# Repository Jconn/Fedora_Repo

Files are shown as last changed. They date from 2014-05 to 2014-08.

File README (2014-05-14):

README file for the MAAV EAGLE git repo

*Do not add gerber files or zip files to the repo

*Edit the .gitignore file with any extensions that for gerber files if encountered

*Don't forget to add your name and email address your local config

*If you find errors in libraries, please fix them imediately or contact the author to report the error.

*You should not trust any of the files in this repo.  PLEASE VERIFY ALL COMPONENTS FOR YOURSELF!

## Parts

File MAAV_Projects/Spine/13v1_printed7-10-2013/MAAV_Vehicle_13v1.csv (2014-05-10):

Part | Value | Device | Package | Description | DIGIEKY# | DIGIKEY | DIGIKEY# | MF | MPN | OC_FARNELL | OC_NEWARK | PARTNUM
C1 | 33pF | C-EUC0402 | C0402 | CAPACITOR, European symbol |  |  | box
C2 | 330uF | C-POL-TANT | C_2917_POL |  |  |  | 478-1811-1-ND
C3 | 0.01uF | C-EUC0603 | C0603 | CAPACITOR, European symbol |  |  | 490-1512-1-ND
C4 | 10uF | C-EUC1206 | C1206 | CAPACITOR, European symbol |  |  | 587-2399-1-ND
C5 | 10uF | C-EUC1206 | C1206 | CAPACITOR, European symbol |  |  | 587-2399-1-ND
C6 | 0.01uF | C-EUC0603 | C0603 | CAPACITOR, European symbol |  |  | 490-1512-1-ND
C7 | 10uF | C-EUC1206 | C1206 | CAPACITOR, European symbol |  |  | 587-2399-1-ND
C8 | 10uF | C-EUC1206 | C1206 | CAPACITOR, European symbol |  |  | 587-2399-1-ND
C9 | 10uF | C-EUC1206 | C1206 | CAPACITOR, European symbol |  |  | 587-2399-1-ND
C10 | 100nF | C-EUC0603 | C0603 | CAPACITOR, European symbol |  |  | 1276-1000-1-ND
C11 | 100nF | C-EUC0603 | C0603 | CAPACITOR, European symbol |  |  | 1276-1000-1-ND
C12 | 100nF | C-EUC0603 | C0603 | CAPACITOR, European symbol |  |  | 1276-1000-1-ND
C13 | 100nF | C-EUC0603 | C0603 | CAPACITOR, European symbol |  |  | 1276-1000-1-ND
C14 | 22pF | C-EUC0603 | C0603 | CAPACITOR, European symbol |  |  | 478-6200-1-ND
C15 | 22pF | C-EUC0603 | C0603 | CAPACITOR, European symbol |  |  | 478-6200-1-ND
C16 | 0.01uF | C-EUC0603 | C0603 | CAPACITOR, European symbol |  |  | 490-1512-1-ND
C17 | 4700pf | C-EUC0402 | C0402 | CAPACITOR, European symbol |  |  | box
C18 | 1uF | C-EUC0603 | C0603 | CAPACITOR, European symbol |  |  | 587-2984-1-ND
C19 | 10uF | C-EUC1206 | C1206 | CAPACITOR, European symbol |  |  | 587-2399-1-ND
C20 | 10uF | C-EUC1206 | C1206 | CAPACITOR, European symbol |  |  | 587-2399-1-ND
C21 | 0.1uF | C-EUC0603 | C0603 | CAPACITOR, European symbol |  |  | 1276-1000-1-ND
C22 | 270pF | C-EUC0402 | C0402 | CAPACITOR, European symbol |  |  | box
C23 | 150uF DNP | T530X157M016ATE015 | C2917 |  |  |  |  |  |  |  |  | 399-4663-1-ND
C24 | 22uF | C-EUC1206 | C1206 | CAPACITOR, European symbol |  |  | 587-3246-1-ND
C25 | 10uF | C-EUC1206 | C1206 | CAPACITOR, European symbol |  |  | 587-2399-1-ND
C26 | 10uF | C-EUC1206 | C1206 | CAPACITOR, European symbol |  |  | 587-2399-1-ND
C27 | 100nF | C-EUC0603 | C0603 | CAPACITOR, European symbol |  |  | 1276-1000-1-ND
C30 | 22uF | C-EUC1206 | C1206 | CAPACITOR, European symbol |  |  | 587-3246-1-ND
C31 | 10uF | C-EUC1206 | C1206 | CAPACITOR, European symbol |  |  | 587-2399-1-ND
C32 | 0.1uF | C-EUC0402 | C0402 | CAPACITOR, European symbol |  |  | box
C33 | 22uF | C-EUC1206 | C1206 | CAPACITOR, European symbol |  |  | 587-3246-1-ND
C34 | 22uF | C-EUC1206 | C1206 | CAPACITOR, European symbol |  |  | 587-3246-1-ND
C35 | 22uF | C-EUC1206 | C1206 | CAPACITOR, European symbol |  |  | 587-3246-1-ND
C36 | 22uF | C-EUC1206 | C1206 | CAPACITOR, European symbol |  |  | 587-3246-1-ND
C37 | 0.1uF | C-EUC0603 | C0603 | CAPACITOR, European symbol |  |  | 490-1524-1-ND
C38 | 0.47uF | C-EUC0805 | C0805 | CAPACITOR, European symbol |  |  | 1276-2966-1-ND
C39 | 0.47uF | C-EUC0805 | C0805 | CAPACITOR, European symbol |  |  | 1276-2966-1-ND
C40 | 0.47uF | C-EUC0805 | C0805 | CAPACITOR, European symbol |  |  | 1276-2966-1-ND
C41 | 0.1uF | C-EUC0603 | C0603 | CAPACITOR, European symbol |  |  | 490-1524-1-ND
C42 | 470uF | C-POL-AL-8-22 | EH22-9 |  | P14440-ND
C43 | 470uF | C-POL-AL-8-22 | EH22-9 |  | P14440-ND
D1 | PDS760 | PDS760 | PDS760 |  |  |  | PDS760DICT-ND
IC3 | PINTO_SMD | PINTO_SMD | PINTO_SMD |  |  |  | S5641-ND (6)
J7 | MA04-1 | MA04-1 | MA-04-SMD |  |  |  | 455-1751-1-ND
J9 | POWER_CONN | POWER_CONN | POWER_CONN |  |  | A30614-ND
L2 | 10uH | DRQ125 | DRQ125 |  |  |  |  |  |  |  |  | 513-1289-1-ND
LED1 | GREEN | LEDCHIPLED_0603 | CHIPLED_0603 | LED |  |  | 1080-1405-1-ND
LED2 | GREEN | LEDCHIPLED_0603 | CHIPLED_0603 | LED |  |  | 1080-1405-1-ND
LED3 | GREEN | LEDCHIPLED_0603 | CHIPLED_0603 | LED |  |  | 1080-1405-1-ND
LED_M0 | GREEN | LEDCHIPLED_0805 | CHIPLED_0805 | LED |  |  | 350-2044-1-ND
LED_M1 | GREEN | LEDCHIPLED_0805 | CHIPLED_0805 | LED |  |  | 350-2044-1-ND
LED_M2 | GREEN | LEDCHIPLED_0805 | CHIPLED_0805 | LED |  |  | 350-2044-1-ND
LED_M3 | GREEN | LEDCHIPLED_0805 | CHIPLED_0805 | LED |  |  | 350-2044-1-ND
Q1 | CRYSTAL_16MHZ_SMD | CRYSTAL_16MHZ_SMD | 4-SMD_DFN |  |  |  | XC1137CT-ND
Q2 | MOSFET-NCHANNELSMD | MOSFET-NCHANNELSMD | SOT23-3 |  |  |  | BSS84CT-ND
Q3 | P-MOSFET-SO8POWER-PAK | P-MOSFET-SO8POWER-PAK | SO-8_POWER-PAK | P-Channel MOSFET |  |  | SI7135DP-T1-GE3CT-ND
Q4 | P-MOSFET-SO8POWER-PAK | P-MOSFET-SO8POWER-PAK | SO-8_POWER-PAK | P-Channel MOSFET |  |  | SI7135DP-T1-GE3CT-ND
Q5 | P-MOSFET-SO8POWER-PAK | P-MOSFET-SO8POWER-PAK | SO-8_POWER-PAK | P-Channel MOSFET |  |  | SI7135DP-T1-GE3CT-ND
Q6 | P-MOSFET-SO8POWER-PAK | P-MOSFET-SO8POWER-PAK | SO-8_POWER-PAK | P-Channel MOSFET |  |  | SI7135DP-T1-GE3CT-ND
Q7 | P-MOSFET-SO8POWER-PAK | P-MOSFET-SO8POWER-PAK | SO-8_POWER-PAK | P-Channel MOSFET |  |  | SI7135DP-T1-GE3CT-ND
Q8 | STL60N3LLH5 | STL60N3LLH5 | POWERFLAT-8 |  |  |  |  |  |  |  |  | 497-11094-1-ND
R1 | 10k | R-USR0603 | R0603 | RESISTOR, American symbol |  |  | P10.0KHCT-ND
R2 | 10k | R-USR0603 | R0603 | RESISTOR, American symbol |  |  | P10.0KHCT-ND
R3 | 10k | R-USR0603 | R0603 | RESISTOR, American symbol |  |  | P10.0KHCT-ND
R4 | 100 | R-USR0402 | R0402 | RESISTOR, American symbol |  |  | box
R5 | 1k | R-USR0603 | R0603 | RESISTOR, American symbol |  |  | P1.00KHCT-ND
R6 | 750 | R-USR0805 | R0805 | RESISTOR, American symbol |  |  | P750CCT-ND
R7 | 10k | R-USR0603 | R0603 | RESISTOR, American symbol |  |  | P10.0KHCT-ND
R8 | 1k | R-USR0603 | R0603 | RESISTOR, American symbol |  |  | P1.00KHCT-ND
R9 | 10k | R-USR0603 | R0603 | RESISTOR, American symbol |  |  | P10.0KHCT-ND
R10 | 10k | R-USR0603 | R0603 | RESISTOR, American symbol |  |  | P10.0KHCT-ND
R11 | 10k | R-USR0603 | R0603 | RESISTOR, American symbol |  |  | P10KDBCT-ND
R12 | 3.16k | R-USR0603 | R0603 | RESISTOR, American symbol |  |  | 311-3.16KDCT-ND
R13 | 10k | R-USR0603 | R0603 | RESISTOR, American symbol |  |  | P10.0KHCT-ND
R14 | 4.7k | R-USR0603 | R0603 | RESISTOR, American symbol |  |  | P4.70KHCT-ND
R15 | 10k | R-USR0603 | R0603 | RESISTOR, American symbol |  |  | P10.0KHCT-ND
R16 | 4.7k | R-USR0603 | R0603 | RESISTOR, American symbol |  |  | P4.70KHCT-ND
R17 | 10k | R-USR0603 | R0603 | RESISTOR, American symbol |  |  | P10.0KHCT-ND
R18 | 4.7k | R-USR0603 | R0603 | RESISTOR, American symbol |  |  | P4.70KHCT-ND
R19 | 10k | R-USR0603 | R0603 | RESISTOR, American symbol |  |  | P10.0KHCT-ND
R20 | 4.7k | R-USR0603 | R0603 | RESISTOR, American symbol |  |  | P4.70KHCT-ND
R21 | 10k | R-USR0603 | R0603 | RESISTOR, American symbol |  |  | P10.0KHCT-ND
R22 | 750 | R-USR0805 | R0805 | RESISTOR, American symbol |  |  | P750CCT-ND
R23 | 750 | R-USR0805 | R0805 | RESISTOR, American symbol |  |  | P750CCT-ND
R24 | 750 | R-USR0805 | R0805 | RESISTOR, American symbol |  |  | P750CCT-ND
R25 | 10k | R-USR0603 | R0603 | RESISTOR, American symbol |  |  | P10.0KHCT-ND
R26 | 10k | R-USR0603 | R0603 | RESISTOR, American symbol |  |  | P10.0KHCT-ND
R27 | 20k | R-USR0402 | R0402 | RESISTOR, American symbol |  |  | box
R28 | 64.9k | R-USR0402 | R0402 | RESISTOR, American symbol |  |  | P64.9KDCCT-ND
R29 | 10k | R-USR0402 | R0402 | RESISTOR, American symbol |  |  | box
R30 | 1k | R-USR0402 | R0402 | RESISTOR, American symbol |  |  | box
R31 | 20k | R-USR0402 | R0402 | RESISTOR, American symbol |  |  | box
R32 | 50 | R-USR0402 | R0402 | RESISTOR, American symbol |  |  | box
R33 | 2.32k | R-USR0402 | R0402 | RESISTOR, American symbol |  |  | P2.32KDCCT-ND
R34 | 27.4k | R-USR0402 | R0402 | RESISTOR, American symbol |  |  | box
R35 | 0.05 | R-US_R2512 | R2512 | RESISTOR, American symbol |  |  | MCS3264R050FERCT-ND
R36 | 10k | R-USR0603 | R0603 | RESISTOR, American symbol |  |  | P10.0KHCT-ND
R37 | 10k | R-USR0603 | R0603 | RESISTOR, American symbol |  |  | P10.0KHCT-ND
R38 | 10k | R-USR0603 | R0603 | RESISTOR, American symbol |  |  | P10.0KHCT-ND
R39 | 10k | R-USR0603 | R0603 | RESISTOR, American symbol |  |  | P10KDBCT-ND
R40 | 432 | R-USR0603 | R0603 | RESISTOR, American symbol |  |  | P432DBCT-ND
R41 |  | R-USR1206 | R1206 | RESISTOR, American symbol |  |  | P100FCT-ND, P68.1FCT-ND, P200FCT-ND
R44 | 750 | R-USR0805 | R0805 | RESISTOR, American symbol |  |  | P750CCT-ND
R47 | 750 | R-USR0805 | R0805 | RESISTOR, American symbol |  |  | P750CCT-ND
R48 | 750 | R-USR0805 | R0805 | RESISTOR, American symbol |  |  | P750CCT-ND
R51 | 10k | R-USR0603 | R0603 | RESISTOR, American symbol |  |  | P10KDBCT-ND
R52 | 432 | R-USR0603 | R0603 | RESISTOR, American symbol |  |  | P432DBCT-ND
S2 | SWITCH-OFF-MOM | SWITCH-OFF-MOM | SWITCH-OFF-MOM |  |  | P11084SCT-ND | P11084SCT-ND
SJ1 | SOLDERJUMPERNO | SOLDERJUMPERNO | SJ_2S-NO | Solder Jumper
SJ2 | SOLDERJUMPERNO | SOLDERJUMPERNO | SJ_2S-NO | Solder Jumper
SJ3 | SOLDERJUMPER_2WAYS | SOLDERJUMPER_2WAYS | SJ_3 | Solder Jumper
SJ4 | SOLDERJUMPER_2WAYS | SOLDERJUMPER_2WAYS | SJ_3 | Solder Jumper
SJ5 | SOLDERJUMPERNO | SOLDERJUMPERNO | SJ_2S-NO | Solder Jumper
SJ6 | SOLDERJUMPER_2WAYS | SOLDERJUMPER_2WAYS | SJ_3 | Solder Jumper
SJ7 | SOLDERJUMPERNO | SOLDERJUMPERNO | SJ_2S-NO | Solder Jumper
SJ8 | SOLDERJUMPER_2WAYS | SOLDERJUMPER_2WAYS | SJ_3 | Solder Jumper
SV1 |  | MA04-1 | MA04-1 | PIN HEADER |  |  |  |  |  | unknown | unknown
SV2 |  | AVRISP-63X2_SMD | AVRISP-6-SMD | PIN HEADER
SV3 |  | MA03-1 | MA03-1 | PIN HEADER |  |  | 3M9477-ND |  |  | unknown | unknown
SV4 |  | MA03-1 | MA03-1 | PIN HEADER |  |  | 3M9477-ND |  |  | unknown | unknown
T1 | MOSFET-NCHANNELSMD | MOSFET-NCHANNELSMD | SOT23-3 |  |  |  | BSS138KCT-ND
T2 | MOSFET-NCHANNELSMD | MOSFET-NCHANNELSMD | SOT23-3 |  |  |  | BSS138KCT-ND
T3 | MOSFET-NCHANNELSMD | MOSFET-NCHANNELSMD | SOT23-3 |  |  |  | BSS138KCT-ND
T4 | MOSFET-NCHANNELSMD | MOSFET-NCHANNELSMD | SOT23-3 |  |  |  | BSS138KCT-ND
T7 | MOSFET-NCHANNELSMD | MOSFET-NCHANNELSMD | SOT23-3 |  |  |  | BSS138KCT-ND
T8 | MOSFET-NCHANNELSMD | MOSFET-NCHANNELSMD | SOT23-3 |  |  |  | BSS138KCT-ND
T9 | MOSFET-NCHANNELSMD | MOSFET-NCHANNELSMD | SOT23-3 |  |  |  | BSS138KCT-ND
T10 | MOSFET-NCHANNELSMD | MOSFET-NCHANNELSMD | SOT23-3 |  |  |  | BSS138KCT-ND
T11 | MOSFET-NCHANNELSMD | MOSFET-NCHANNELSMD | SOT23-3 |  |  |  | BSS138KCT-ND
U$1 | INDUCTOR | INDUCTOR | CDRH127 |  | 308-1333-1-ND | 308-1333-1-ND
U$2 | SWITCH_DPDT | SWITCH_DPDT | SWITCH_VERT_DPDT |  |  |  | AS22AV-ND
U$3 | ESC_CONN | ESC_CONN | ESC_CONN
U$4 | ESC_CONN | ESC_CONN | ESC_CONN
U$5 | ESC_CONN | ESC_CONN | ESC_CONN
U$6 | ESC_CONN | ESC_CONN | ESC_CONN
U$9 | DIODE-SCHOTTKYBIG | DIODE-SCHOTTKYBIG | DO-214AB,SMC |  |  |  | B540C-FDICT-ND
U$10 | TRANSISTOR_NPN_DPAK | TRANSISTOR_NPN_DPAK | DPAK |  |  |  | 497-12849-1-ND
U$11 | MAX3221-RS232 | MAX3221-RS232 | 16-TSSOP |  |  |  | 296-19825-1-ND
U$12 | POWER_HOLES | POWER_HOLES | POWER_HOLES
U$13 | BATTERY50A | BATTERY50A | LIPO_POWER_50A
U$14 | M02_SCREW_0.1 | M02_SCREW_0.1 | SCREW_TERM_2POS |  |  |  | A98333-ND
U$15 | MOSFET-PCHANNEL_SOT23-3 | MOSFET-PCHANNEL_SOT23-3 | SOT23-3 |  |  |  | BSS84CT-ND
U1 | LM5022 | LM5022 | MSOP-10 |  |  |  |  |  |  |  |  | LM5022MM/NOPBCT-ND
U2 | TPS5450 | TPS5450 | TPS5450 |  |  | 296-23750-1-ND | 296-23750-1-ND
U3 | ATMEGA328-AU | ATMEGA328-AU | 32-TQFP |  |  | ATMEGA328-AU-ND | ATMEGA328-AU-ND
U4 | REG_3V_8SOIC | REG_3V_8SOIC | 8-SOIC |  |  | 296-2719-5-ND | 296-2719-5-ND

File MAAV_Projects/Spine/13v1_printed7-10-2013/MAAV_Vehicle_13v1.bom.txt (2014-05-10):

Partlist exported from H:/EAGLE/MAAV/Spine/13v1_printed7-10-2013/MAAV_Vehicle_13v1.sch at 7/13/2013 7:53:38 PMPartlist exported from H:/EAGLE/MAAV/Spine/13v1_printed7-10-2013/MAAV_Vehicle_13v1.sch at 7/13/2013 7:53:38 PM

10,B540C-FDICT-ND
10,A98333-ND
10,296-19825-1-ND
10,BSS84CT-ND
10,AS22AV-ND
10,497-12849-1-ND
10,box
30,490-1524-1-ND
30,490-1512-1-ND
30,1276-2966-1-ND
10,587-2984-1-ND
100,587-2399-1-ND
20,478-6200-1-ND
60,587-3246-1-ND
10,box
50,478-1239-1-ND
10,box
10,478-1811-1-ND
10,box
10,PDS760DICT-ND
10,S5641-ND (6)
10,455-1751-1-ND
30,1080-1405-1-ND
40,350-2044-1-ND
10,XC1137CT-ND
100,BSS84CT-ND
50,SI7135DP-T1-GE3CT-ND
10,P100FCT-ND, P68.1FCT-ND, P200FCT-ND
10,MCS3264R050FERCT-ND
10,box
20,P1.00KHCT-ND
10,P2.32KDCCT-ND
10,311-3.16KDCT-ND
40,P4.70KHCT-ND
10,box
190,P10.0KHCT-ND
20,box
10,box
10,box
10,P64.9KDCCT-ND
10,box
20,P432DBCT-ND
70,P750CCT-ND
10,P11084SCT-ND
20,3M9477-ND
10,ATMEGA328-AU-ND
10,296-2719-5-ND
10,296-23750-1-ND

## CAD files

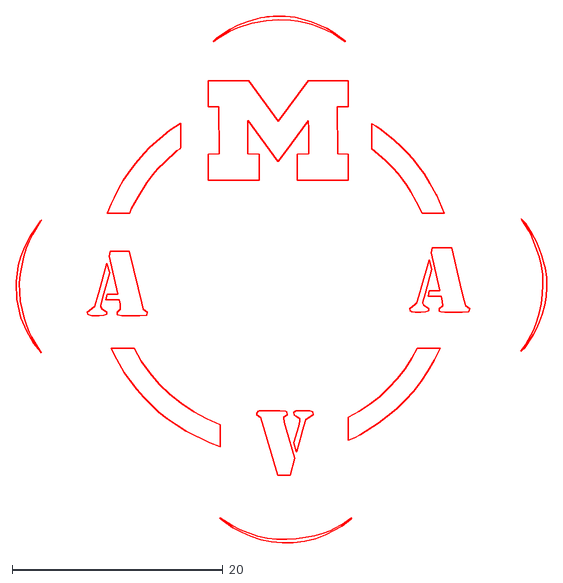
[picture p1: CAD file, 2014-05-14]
Graphics/MAAV Vector Logo.dxf
50.4 x 50.0

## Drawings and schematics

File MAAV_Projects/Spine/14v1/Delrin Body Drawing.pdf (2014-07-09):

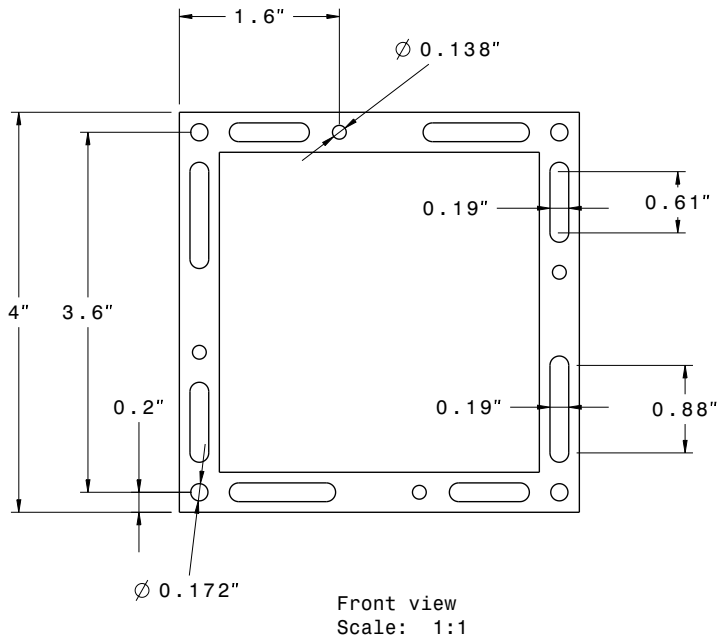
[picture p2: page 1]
Front view Scale: 1:1

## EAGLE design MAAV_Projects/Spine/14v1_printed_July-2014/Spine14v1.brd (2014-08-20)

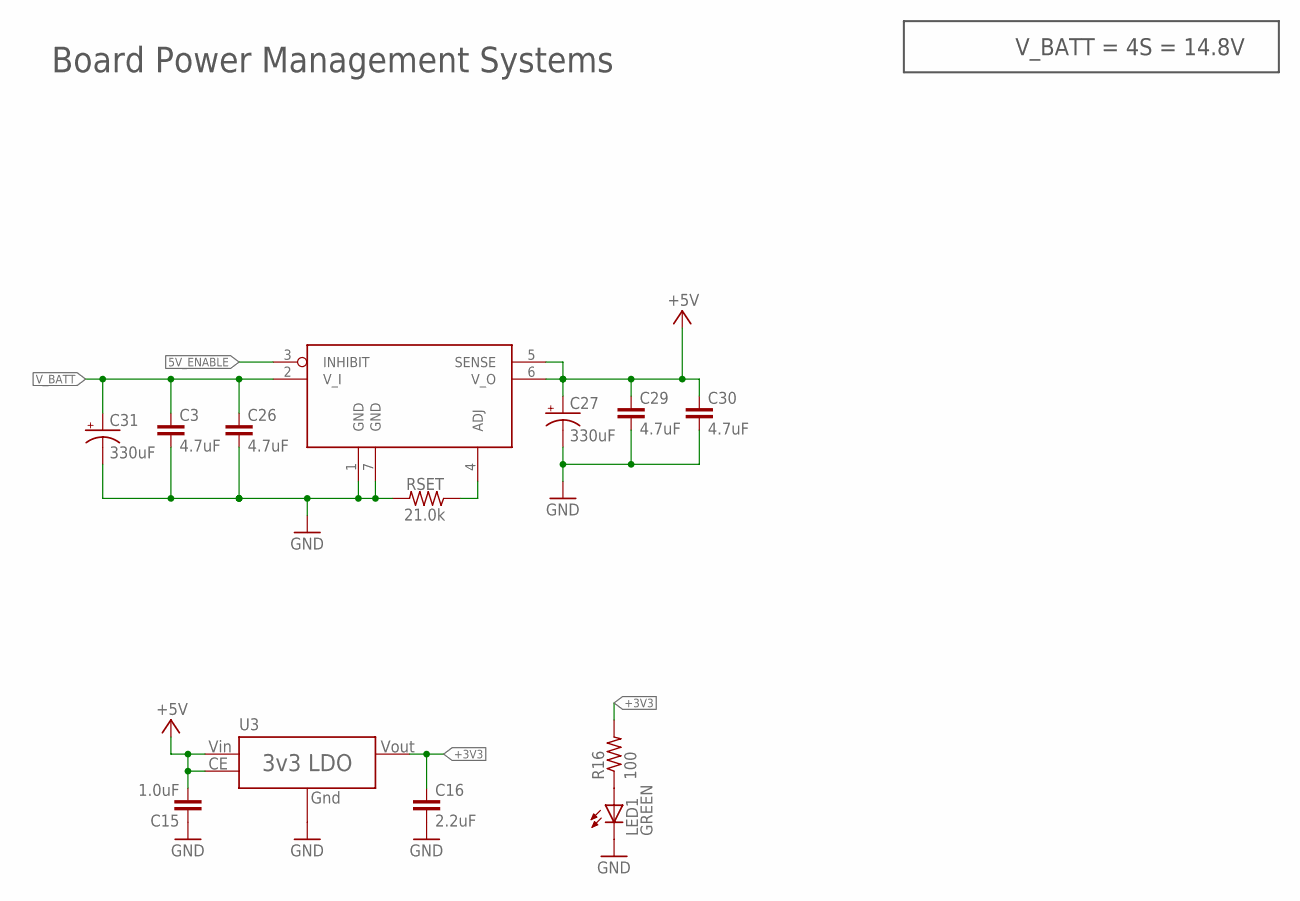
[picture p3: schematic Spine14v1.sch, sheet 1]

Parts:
C3, C26, C29, C30: 4.7uF; C1206; DIGIKEY# 587-2994-1-ND
C15: 1.0uF; C0805
C16: 2.2uF; C0805
C27, C31: 330uF; PANASONIC_F; DIGIKEY PCE3779CT-ND
LED1: GREEN; CHIPLED_0603
R16: 100; R0603
RSET: 21.0k; R0603
U3: XC6210; SOT-25
U$5: POWER-MODULE-TI-6A_SOLDERLESS_TERMINAL; POWER-MOD-TI-6A-SOLDERLESS-TERMINAL

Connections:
5V_ENABLE: U$5.3 (INHIBIT); also elsewhere on the board
+3V3: C16.1, R16.2, U3.5 (VOUT); also elsewhere on the board
+5V: C15.2, C27.+, C29.1, C30.1, U3.1 (VIN), U3.3 (CE), U$5.5 (SENSE), U$5.6 (V_O); also elsewhere on the board
GND: C3.2, C15.1, C16.2, C26.2, C27.-, C29.2, C30.2, C31.-, LED1.C, RSET.2, U3.2 (GND), U$5.1 (GND), U$5.7 (GND); also elsewhere on the board
unnamed: LED1.A, R16.1
unnamed: RSET.1, U$5.4 (ADJ)
V_BATT: C3.1, C26.1, C31.+, U$5.2 (V_I); also elsewhere on the board

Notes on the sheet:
Board Power Management Systems
V_BATT = 4S = 14.8V

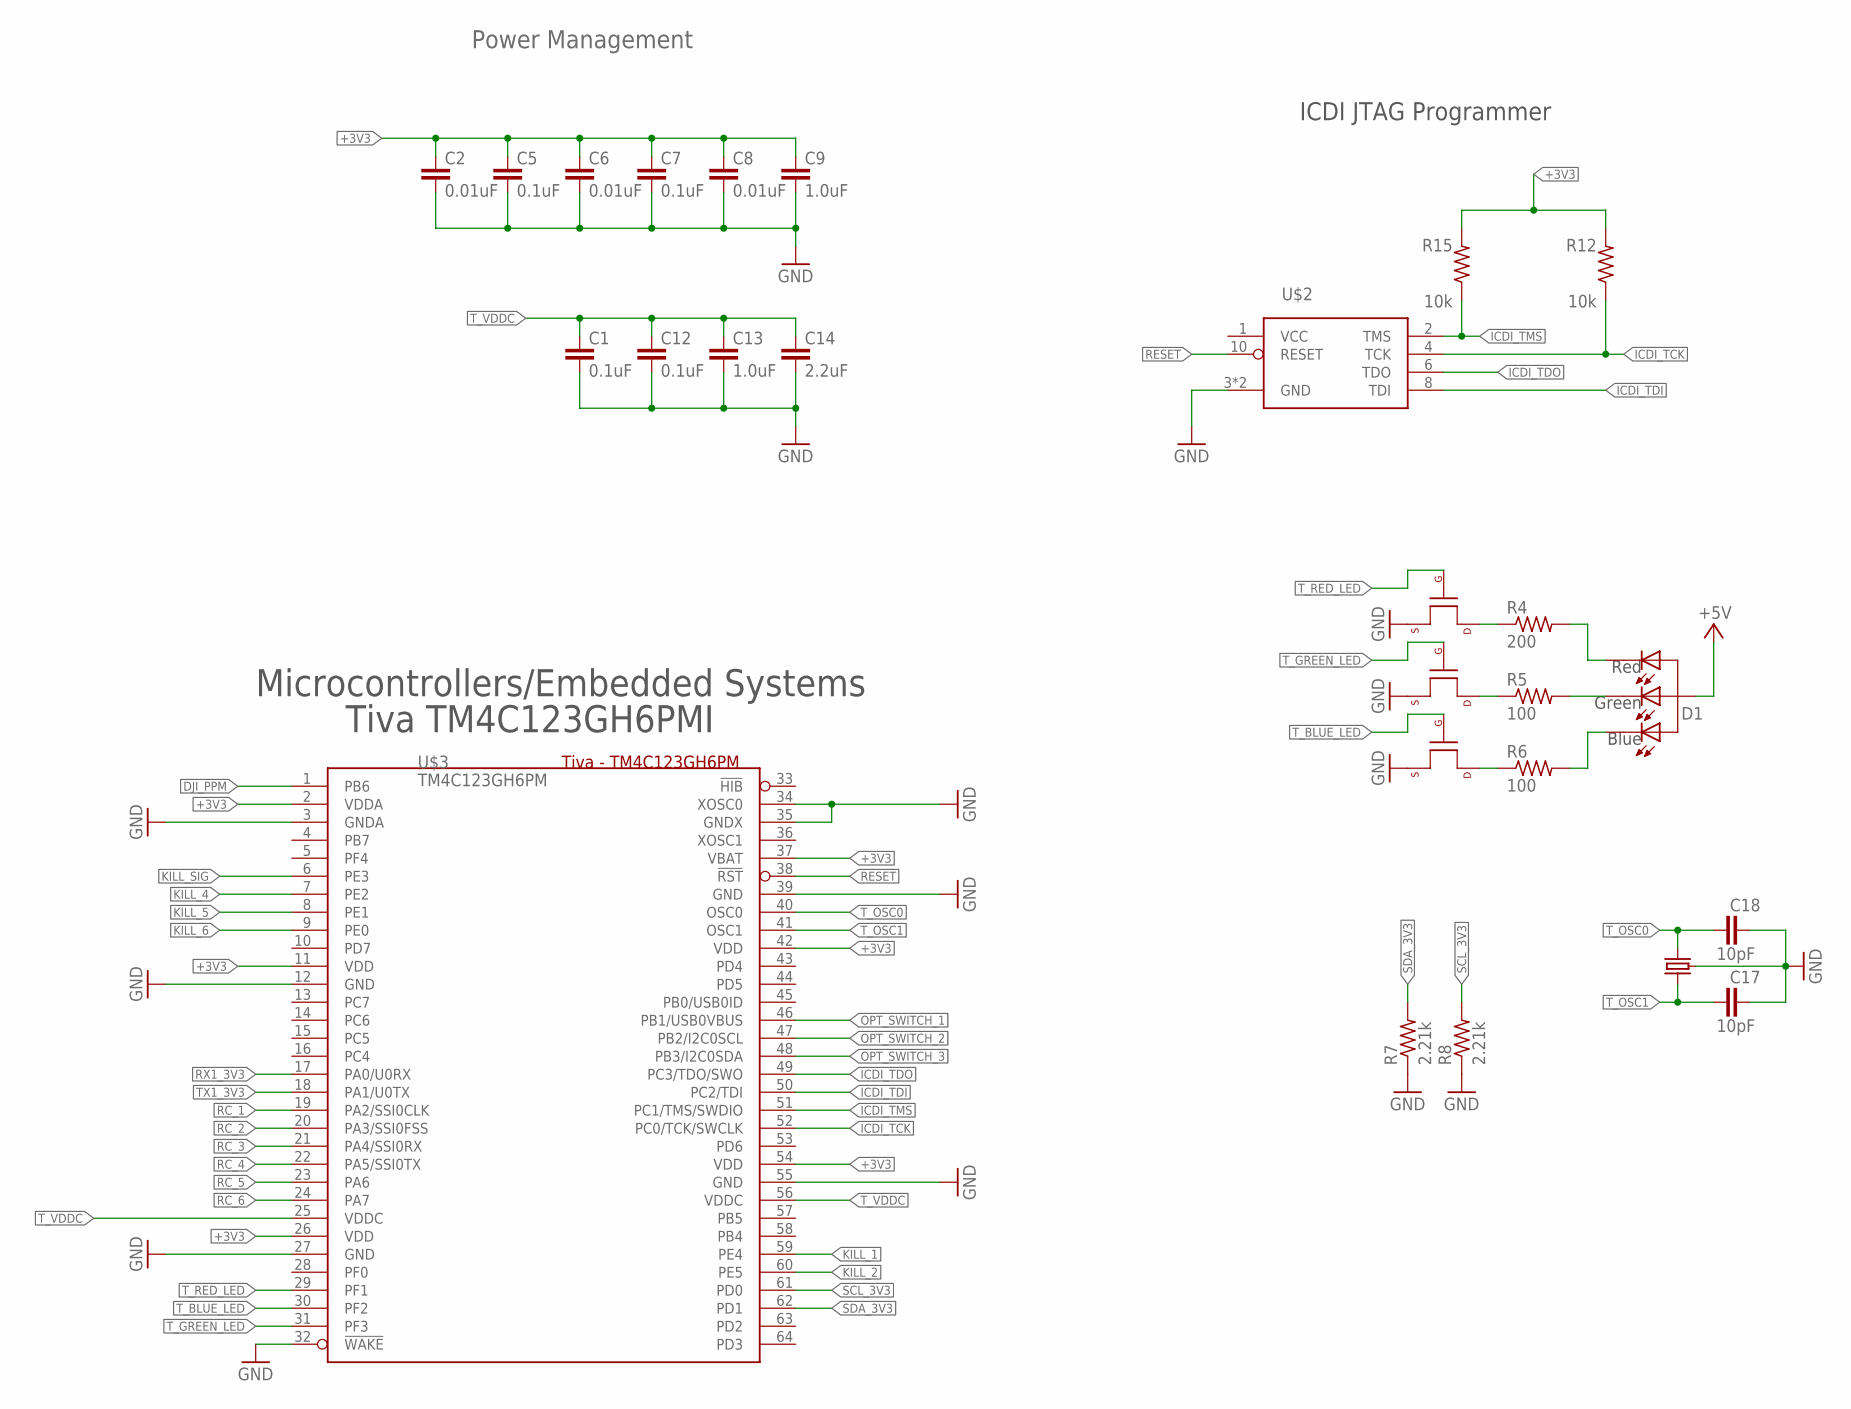
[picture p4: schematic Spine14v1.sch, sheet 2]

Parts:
C1, C5, C7, C12: 0.1uF; C0603
C2, C6, C8: 0.01uF; C0603
C9: 1.0uF; C0603
C13: 1.0uF; C0805
C14: 2.2uF; C0805
C17, C18: 10pF; C0603; DIGIKEY# 399-1049-1-ND
D1: LED_RGB_CA; LED_RGB_0606
Q2, Q3, Q4: MOSFET-NCHANNELSMD; SOT23-3; DIGIKEY# BSN20-7DICT-ND
R4: 200; R0603
R5, R6: 100; R0603
R7, R8: 2.21k; R0603
R12, R15: 10k; R0603
U$1: CRYSTAL_403C11E16; 4-SMD-SWITCH
U$2: JTAG-ARM_TC-10; TC2050-IDC
U$3: TM4C123GH6PM; DIGIKEY# 296-35849-ND

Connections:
+3V3: C2.1, C5.1, C6.1, C7.1, C8.1, C9.1, R12.2, R15.2, U$3.2 (VDDA), U$3.11 (VDD), U$3.26 (VDD), U$3.37 (VBAT), U$3.42 (VDD), U$3.54 (VDD); also elsewhere on the board
+5V: D1.1 (A); also elsewhere on the board
DJI_PPM: U$3.1 (PB6); also elsewhere on the board
GND: C1.2, C2.2, C5.2, C6.2, C7.2, C8.2, C9.2, C12.2, C13.2, C14.2, C17.2, C18.2, Q2.2 (S), Q3.2 (S), Q4.2 (S), R7.1, R8.1, U$1.2 (GND), U$1.4 (GND), U$2.3 (GND), U$2.9 (GND), U$3.3 (GNDA), U$3.12 (GND), U$3.27 (GND), U$3.32 (!WAKE), U$3.34 (XOSC0), U$3.35 (GNDX), U$3.39 (GND), U$3.55 (GND); also elsewhere on the board
ICDI_TCK: R12.1, U$2.4 (TCK), U$3.52 (PC0/TCK/SWCLK)
ICDI_TDI: U$2.8 (TDI), U$3.50 (PC2/TDI)
ICDI_TDO: U$2.6 (TDO), U$3.49 (PC3/TDO/SWO)
ICDI_TMS: R15.1, U$2.2 (TMS), U$3.51 (PC1/TMS/SWDIO)
KILL_1: U$3.59 (PE4); also elsewhere on the board
KILL_2: U$3.60 (PE5); also elsewhere on the board
KILL_4: U$3.7 (PE2); also elsewhere on the board
KILL_5: U$3.8 (PE1); also elsewhere on the board
KILL_6: U$3.9 (PE0); also elsewhere on the board
KILL_SIG: U$3.6 (PE3); also elsewhere on the board
unnamed: Q4.3 (D), R4.1
unnamed: Q3.3 (D), R5.1
unnamed: Q2.3 (D), R6.1
unnamed: D1.2 (R), R4.2
unnamed: D1.3 (G), R5.2
unnamed: D1.4 (B), R6.2
OPT_SWITCH_1: U$3.46 (PB1/USB0VBUS); also elsewhere on the board
OPT_SWITCH_2: U$3.47 (PB2/I2C0SCL); also elsewhere on the board
OPT_SWITCH_3: U$3.48 (PB3/I2C0SDA); also elsewhere on the board
RC_1: U$3.19 (PA2/SSI0CLK); also elsewhere on the board
RC_2: U$3.20 (PA3/SSI0FSS); also elsewhere on the board
RC_3: U$3.21 (PA4/SSI0RX); also elsewhere on the board
RC_4: U$3.22 (PA5/SSI0TX); also elsewhere on the board
RC_5: U$3.23 (PA6); also elsewhere on the board
RC_6: U$3.24 (PA7); also elsewhere on the board
RESET: U$2.10 (RESET), U$3.38 (!RST); also elsewhere on the board
RX1_3V3: U$3.17 (PA0/U0RX); also elsewhere on the board
SCL_3V3: R8.2, U$3.61 (PD0); also elsewhere on the board
SDA_3V3: R7.2, U$3.62 (PD1); also elsewhere on the board
TX1_3V3: U$3.18 (PA1/U0TX); also elsewhere on the board
T_BLUE_LED: Q2.1 (G), U$3.30 (PF2)
T_GREEN_LED: Q3.1 (G), U$3.31 (PF3)
T_OSC0: C18.1, U$1.3 (2), U$3.40 (OSC0)
T_OSC1: C17.1, U$1.1, U$3.41 (OSC1)
T_RED_LED: Q4.1 (G), U$3.29 (PF1)
T_VDDC: C1.1, C12.1, C13.1, C14.1, U$3.25 (VDDC), U$3.56 (VDDC)

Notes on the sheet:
Microcontrollers/Embedded Systems
Power Management
Tiva TM4C123GH6PMI
ICDI JTAG Programmer

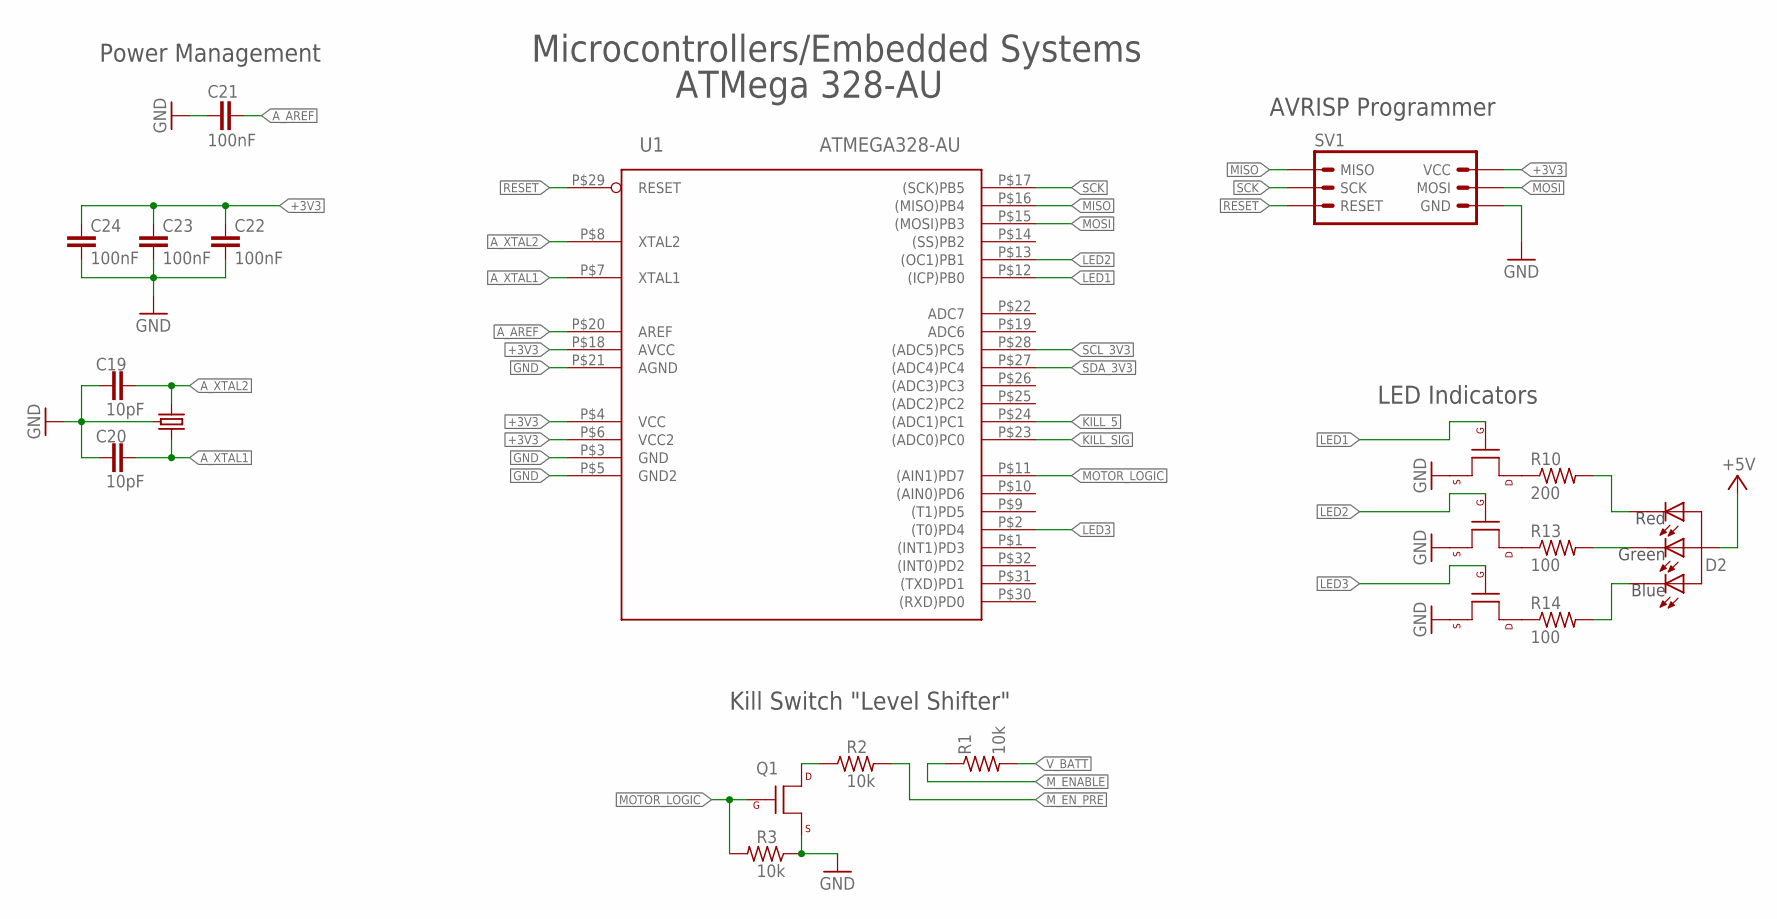
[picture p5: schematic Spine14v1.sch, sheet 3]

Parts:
C19, C20: 10pF; C0603; DIGIKEY# 399-1049-1-ND
C21, C22, C23, C24: 100nF; C0603; DIGIKEY# 1276-1000-1-ND
D2: LED_RGB_CA; LED_RGB_0606
Q1, Q6, Q7, Q8: MOSFET-NCHANNELSMD; SOT23-3; DIGIKEY# BSN20-7DICT-ND
R1, R2, R3: 10k; R0603
R10: 200; R0603
R13, R14: 100; R0603
SV1: AVRISP-6_3X2_PLUG_OF_NAILS; TC2030-IDC
U1: ATMEGA328-AU; 32-TQFP; DIGIKEY# ATMEGA328-AU-ND
U$6: CRYSTAL_403C11E16; 4-SMD-SWITCH

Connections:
+3V3: C22.1, C23.1, C24.1, SV1.6 (VCC), U1.P$4 (VCC), U1.P$6 (VCC2), U1.P$18 (AVCC); also elsewhere on the board
+5V: D2.1 (A); also elsewhere on the board
A_AREF: C21.1, U1.P$20 (AREF)
A_XTAL1: C20.2, U1.P$7 (XTAL1), U$6.3 (2)
A_XTAL2: C19.2, U1.P$8 (XTAL2), U$6.1
GND: C19.1, C20.1, C21.2, C22.2, C23.2, C24.2, Q1.2 (S), Q6.2 (S), Q7.2 (S), Q8.2 (S), R3.1, SV1.4 (GND), U1.P$3 (GND), U1.P$5 (GND2), U1.P$21 (AGND), U$6.2 (GND), U$6.4 (GND); also elsewhere on the board
KILL_5: U1.P$24 ((ADC1)PC1); also elsewhere on the board
KILL_SIG: U1.P$23 ((ADC0)PC0); also elsewhere on the board
LED1: Q8.1 (G), U1.P$12 ((ICP)PB0)
LED2: Q7.1 (G), U1.P$13 ((OC1)PB1)
LED3: Q6.1 (G), U1.P$2 ((T0)PD4)
MISO: SV1.1 (MISO), U1.P$16 ((MISO)PB4)
MOSI: SV1.5 (MOSI), U1.P$15 ((MOSI)PB3)
MOTOR_LOGIC: Q1.1 (G), R3.2, U1.P$11 ((AIN1)PD7)
M_ENABLE: R1.1; also elsewhere on the board
M_EN_PRE: R2.2; also elsewhere on the board
unnamed: Q1.3 (D), R2.1
unnamed: Q8.3 (D), R10.1
unnamed: Q7.3 (D), R13.1
unnamed: Q6.3 (D), R14.1
unnamed: D2.2 (R), R10.2
unnamed: D2.3 (G), R13.2
unnamed: D2.4 (B), R14.2
RESET: SV1.3 (RESET), U1.P$29 (RESET); also elsewhere on the board
SCK: SV1.2 (SCK), U1.P$17 ((SCK)PB5)
SCL_3V3: U1.P$28 ((ADC5)PC5); also elsewhere on the board
SDA_3V3: U1.P$27 ((ADC4)PC4); also elsewhere on the board
V_BATT: R1.2; also elsewhere on the board

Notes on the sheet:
Microcontrollers/Embedded Systems
ATMega 328-AU
AVRISP Programmer
Power Management
LED Indicators
Kill Switch "Level Shifter"

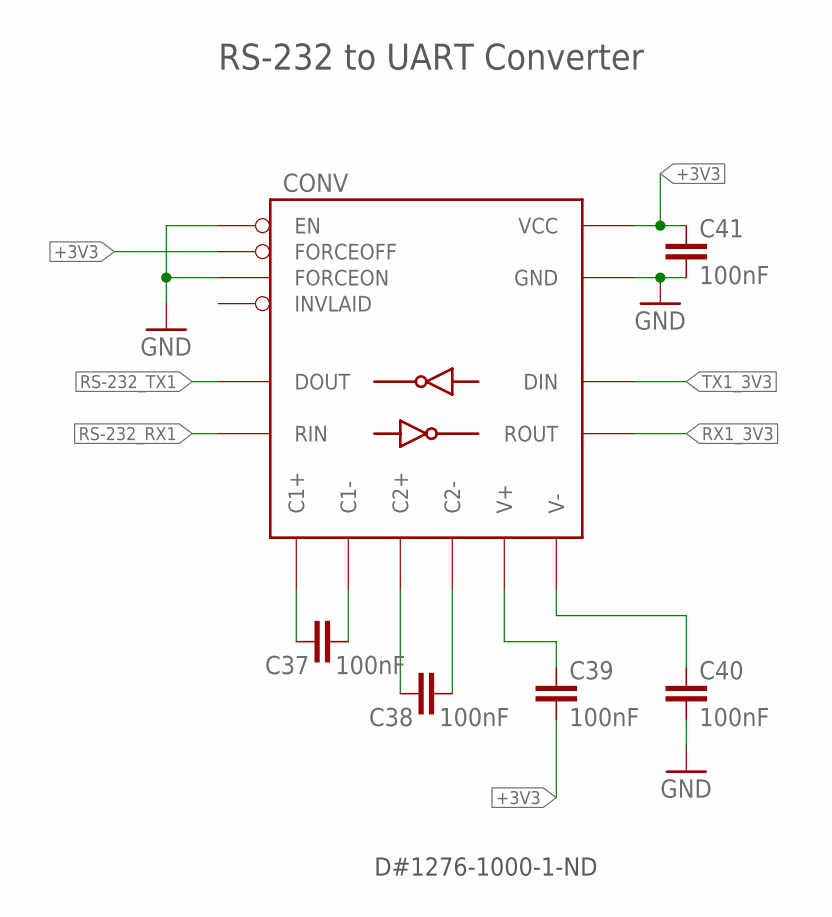
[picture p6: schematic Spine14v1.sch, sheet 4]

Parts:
C37, C41: 100nF; C0603; DIGIKEY# 1276-1000-1-ND
C38, C39, C40: 100nF; C0805
CONV: MAX3221-RS232; 16-TSSOP; DIGIKEY# 296-19825-1-ND

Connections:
+3V3: C39.2, C41.1, CONV.P$15 (VCC), CONV.P$16 (FORCEOFF); also elsewhere on the board
GND: C40.2, C41.2, CONV.P$1 (EN), CONV.P$12 (FORCEON), CONV.P$14 (GND); also elsewhere on the board
unnamed: C37.1, CONV.P$2 (C1+)
unnamed: C39.1, CONV.P$3 (V+)
unnamed: C40.1, CONV.P$7 (V-)
unnamed: C37.2, CONV.P$4 (C1-)
unnamed: C38.1, CONV.P$5 (C2+)
unnamed: C38.2, CONV.P$6 (C2-)
RS-232_RX1: CONV.P$8 (RIN); also elsewhere on the board
RS-232_TX1: CONV.P$13 (DOUT); also elsewhere on the board
RX1_3V3: CONV.P$9 (ROUT); also elsewhere on the board
TX1_3V3: CONV.P$11 (DIN); also elsewhere on the board

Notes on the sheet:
RS-232 to UART Converter
D#1276-1000-1-ND

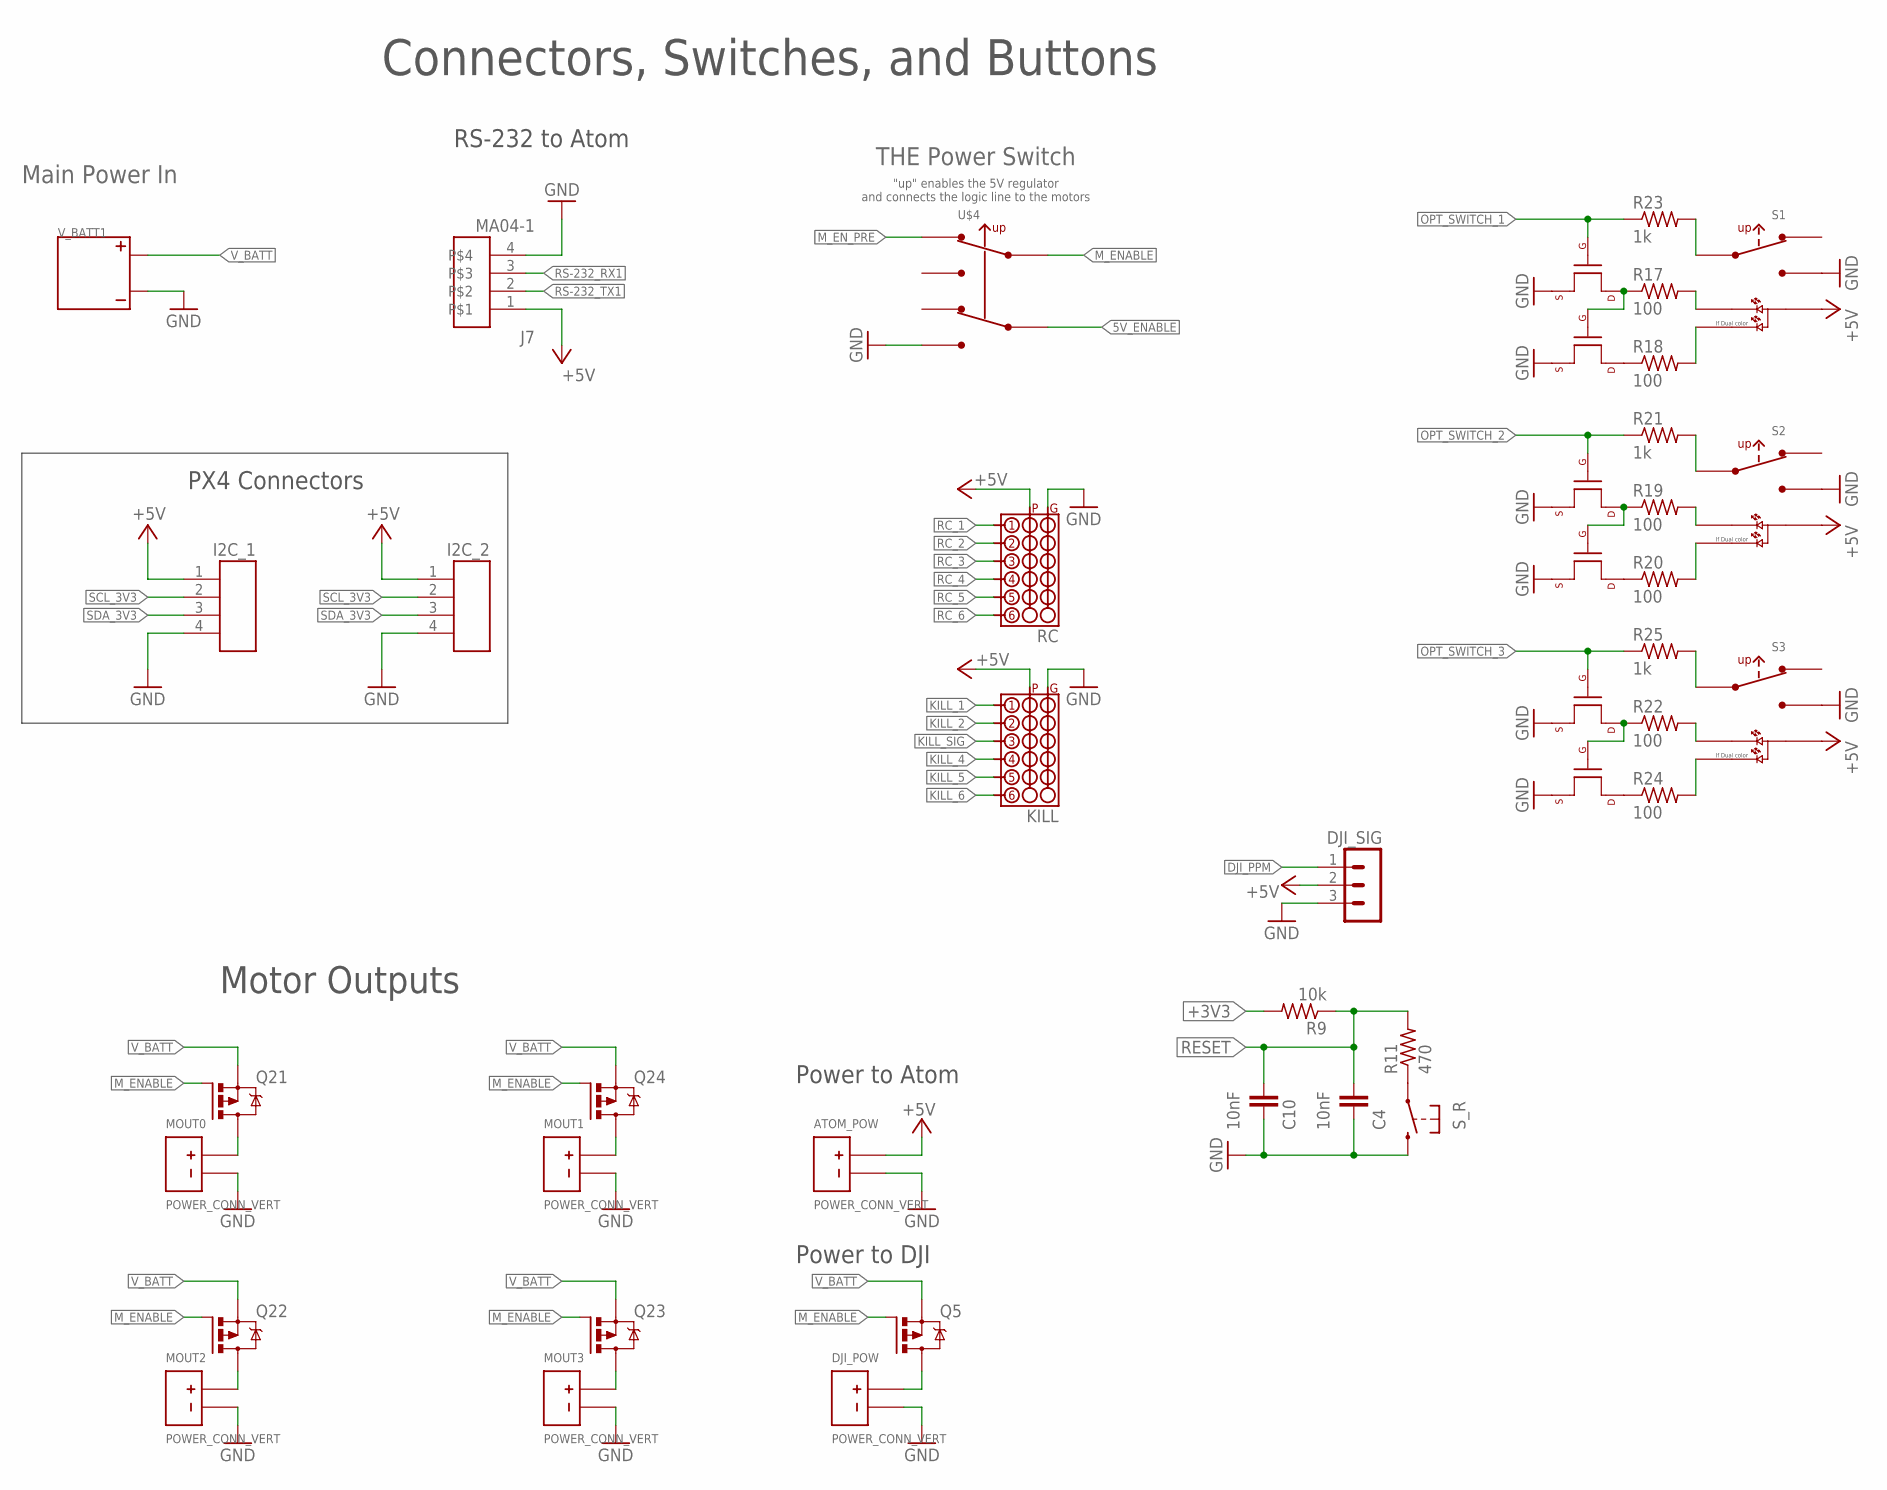
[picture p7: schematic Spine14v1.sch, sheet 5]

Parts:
ATOM_POW: POWER_CONN_VERT; POWER_CONN
C4, C10: 10nF; C0603
DJI_POW: POWER_CONN_VERT; POWER_CONN
DJI_SIG: MA03-1
I2C_1, I2C_2: CONN_HEADER_4POS_RIGHT_ANGLE_I2C; CONN_HEADER_4POS_1.25MM_SMD
J7: MA04-1; MA-04-SMD
KILL: RC_RECIEVER_RECEP
MOUT0, MOUT1, MOUT2, MOUT3: POWER_CONN_VERT; POWER_CONN
Q5, Q21, Q22, Q23, Q24: P-MOSFET-SO8POWER-PAK; SO-8_POWER-PAK
Q9, Q10, Q11, Q12, Q13, Q14: MOSFET-NCHANNELSMD; SOT23-3; DIGIKEY# BSN20-7DICT-ND
R9: 10k; R0603
R11: 470; R0603
R17, R18, R19, R20, R22, R24: 100; R0603
R21, R23, R25: 1k; R0603
RC: RC_RECIEVER_RECEP
S1, S2, S3: SWITCH_SPDT_ILUMINATED_2COLOR_VERT_ILLUMINATED; NKK_VERT_SWITCH_6PIN
S_R: TACT_BUTTONSMD; TACT-MOM-SMD
U$4: JON_LIB_SWITCH_DPDT; JON_LIB_SWITCH_VERT_DPDT
V_BATT1: BATT-CONN-50A_MINI-FIT-SR_THRU-HOLE; BATT-CONN-50A

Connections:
5V_ENABLE: U$4.P$5; also elsewhere on the board
+3V3: R9.2; also elsewhere on the board
+5V: ATOM_POW.P1, DJI_SIG.2, I2C_1.1, I2C_2.1, J7.1, KILL.VCC, KILL.VCC2 (VCC), RC.VCC, RC.VCC2 (VCC), S1.P$5, S2.P$5, S3.P$5; also elsewhere on the board
DJI_PPM: DJI_SIG.1; also elsewhere on the board
GND: ATOM_POW.P2 (N), C4.2, C10.2, DJI_POW.P2 (N), DJI_SIG.3, I2C_1.4, I2C_2.4, J7.4, KILL.GND, KILL.GND2 (GND), MOUT0.P2 (N), MOUT1.P2 (N), MOUT2.P2 (N), MOUT3.P2 (N), Q9.2 (S), Q10.2 (S), Q11.2 (S), Q12.2 (S), Q13.2 (S), Q14.2 (S), RC.GND, RC.GND2 (GND), S1.P$1, S2.P$1, S3.P$1, S_R.S, S_R.S1 (S), U$4.P$6, V_BATT1.GND-1 (GND), V_BATT1.GND-2 (GND); also elsewhere on the board
KILL_1: KILL.P$1; also elsewhere on the board
KILL_2: KILL.P$2; also elsewhere on the board
KILL_4: KILL.P$4; also elsewhere on the board
KILL_5: KILL.P$5; also elsewhere on the board
KILL_6: KILL.P$6; also elsewhere on the board
KILL_SIG: KILL.P$3; also elsewhere on the board
M_ENABLE: Q5.G, Q21.G, Q22.G, Q23.G, Q24.G, U$4.P$2; also elsewhere on the board
M_EN_PRE: U$4.P$1; also elsewhere on the board
unnamed: MOUT0.P1, Q21.D1, Q21.D2 (D1), Q21.D3 (D1), Q21.D4 (D1), Q21.D5 (D1)
unnamed: Q9.1 (G), Q10.3 (D), R17.1
unnamed: R11.1, S_R.P, S_R.P1
unnamed: MOUT1.P1, Q24.D1, Q24.D2 (D1), Q24.D3 (D1), Q24.D4 (D1), Q24.D5 (D1)
unnamed: MOUT2.P1, Q22.D1, Q22.D2 (D1), Q22.D3 (D1), Q22.D4 (D1), Q22.D5 (D1)
unnamed: MOUT3.P1, Q23.D1, Q23.D2 (D1), Q23.D3 (D1), Q23.D4 (D1), Q23.D5 (D1)
unnamed: DJI_POW.P1, Q5.D1, Q5.D2 (D1), Q5.D3 (D1), Q5.D4 (D1), Q5.D5 (D1)
unnamed: Q9.3 (D), R18.1
unnamed: Q11.1 (G), Q12.3 (D), R19.1
unnamed: Q11.3 (D), R20.1
unnamed: R19.2, S2.P$6
unnamed: R20.2, S2.P$4
unnamed: R23.2, S1.P$2
unnamed: R21.2, S2.P$2
unnamed: R17.2, S1.P$6
unnamed: R18.2, S1.P$4
unnamed: Q13.1 (G), Q14.3 (D), R22.1
unnamed: Q13.3 (D), R24.1
unnamed: R22.2, S3.P$6
unnamed: R24.2, S3.P$4
unnamed: R25.2, S3.P$2
OPT_SWITCH_1: Q10.1 (G), R23.1; also elsewhere on the board
OPT_SWITCH_2: Q12.1 (G), R21.1; also elsewhere on the board
OPT_SWITCH_3: Q14.1 (G), R25.1; also elsewhere on the board
RC_1: RC.P$1; also elsewhere on the board
RC_2: RC.P$2; also elsewhere on the board
RC_3: RC.P$3; also elsewhere on the board
RC_4: RC.P$4; also elsewhere on the board
RC_5: RC.P$5; also elsewhere on the board
RC_6: RC.P$6; also elsewhere on the board
RESET: C4.1, C10.1, R9.1, R11.2; also elsewhere on the board
RS-232_RX1: J7.3; also elsewhere on the board
RS-232_TX1: J7.2; also elsewhere on the board
SCL_3V3: I2C_1.2, I2C_2.2; also elsewhere on the board
SDA_3V3: I2C_1.3, I2C_2.3; also elsewhere on the board
V_BATT: Q5.S1, Q5.S2 (S1), Q5.S3 (S1), Q21.S1, Q21.S2 (S1), Q21.S3 (S1), Q22.S1, Q22.S2 (S1), Q22.S3 (S1), Q23.S1, Q23.S2 (S1), Q23.S3 (S1), Q24.S1, Q24.S2 (S1), Q24.S3 (S1), V_BATT1.VCC-1 (VCC), V_BATT1.VCC-2 (VCC); also elsewhere on the board

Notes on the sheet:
Connectors, Switches, and Buttons
"up" enables the 5V regulator and connects the logic line to the motors
Main Power In
THE Power Switch
Motor Outputs
PX4 Connectors
RS-232 to Atom
Power to Atom
Power to DJI

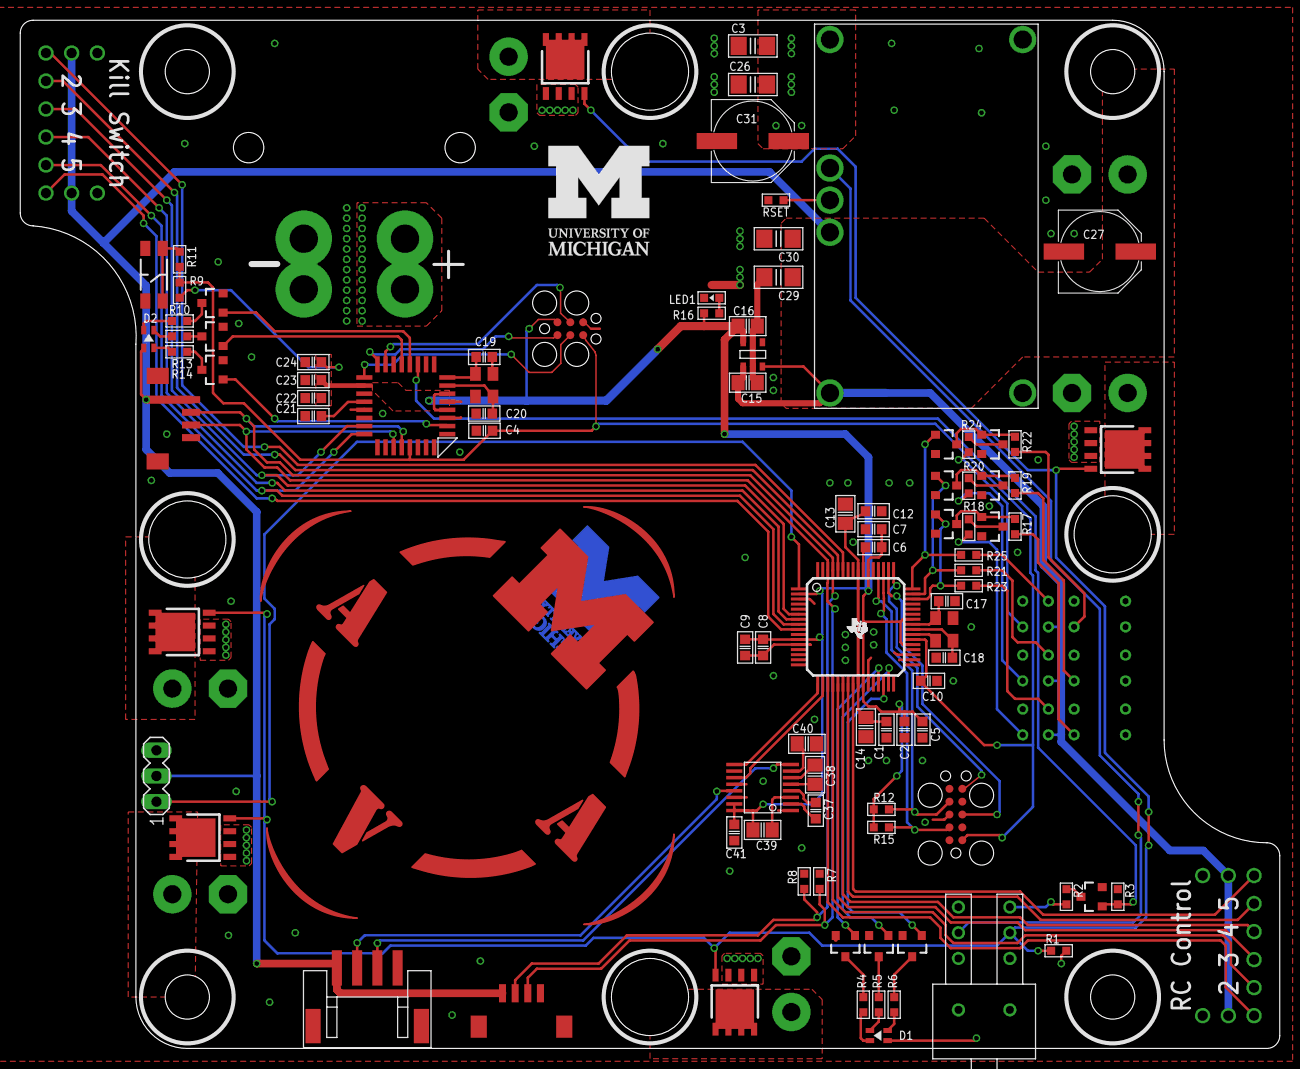
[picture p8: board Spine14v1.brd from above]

Board: 4 copper layers, 124.5 x 101.6 mm, 110 parts (1 on the bottom side), 92 nets.

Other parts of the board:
U$7: BLOCK-M-DOUBLE-STACKED-10MM-MASK
U$8: MAAVLOGO_50MM_MASK_ONLY
U$9: BLOCK-M-DOUBLE-STACKED-10MM

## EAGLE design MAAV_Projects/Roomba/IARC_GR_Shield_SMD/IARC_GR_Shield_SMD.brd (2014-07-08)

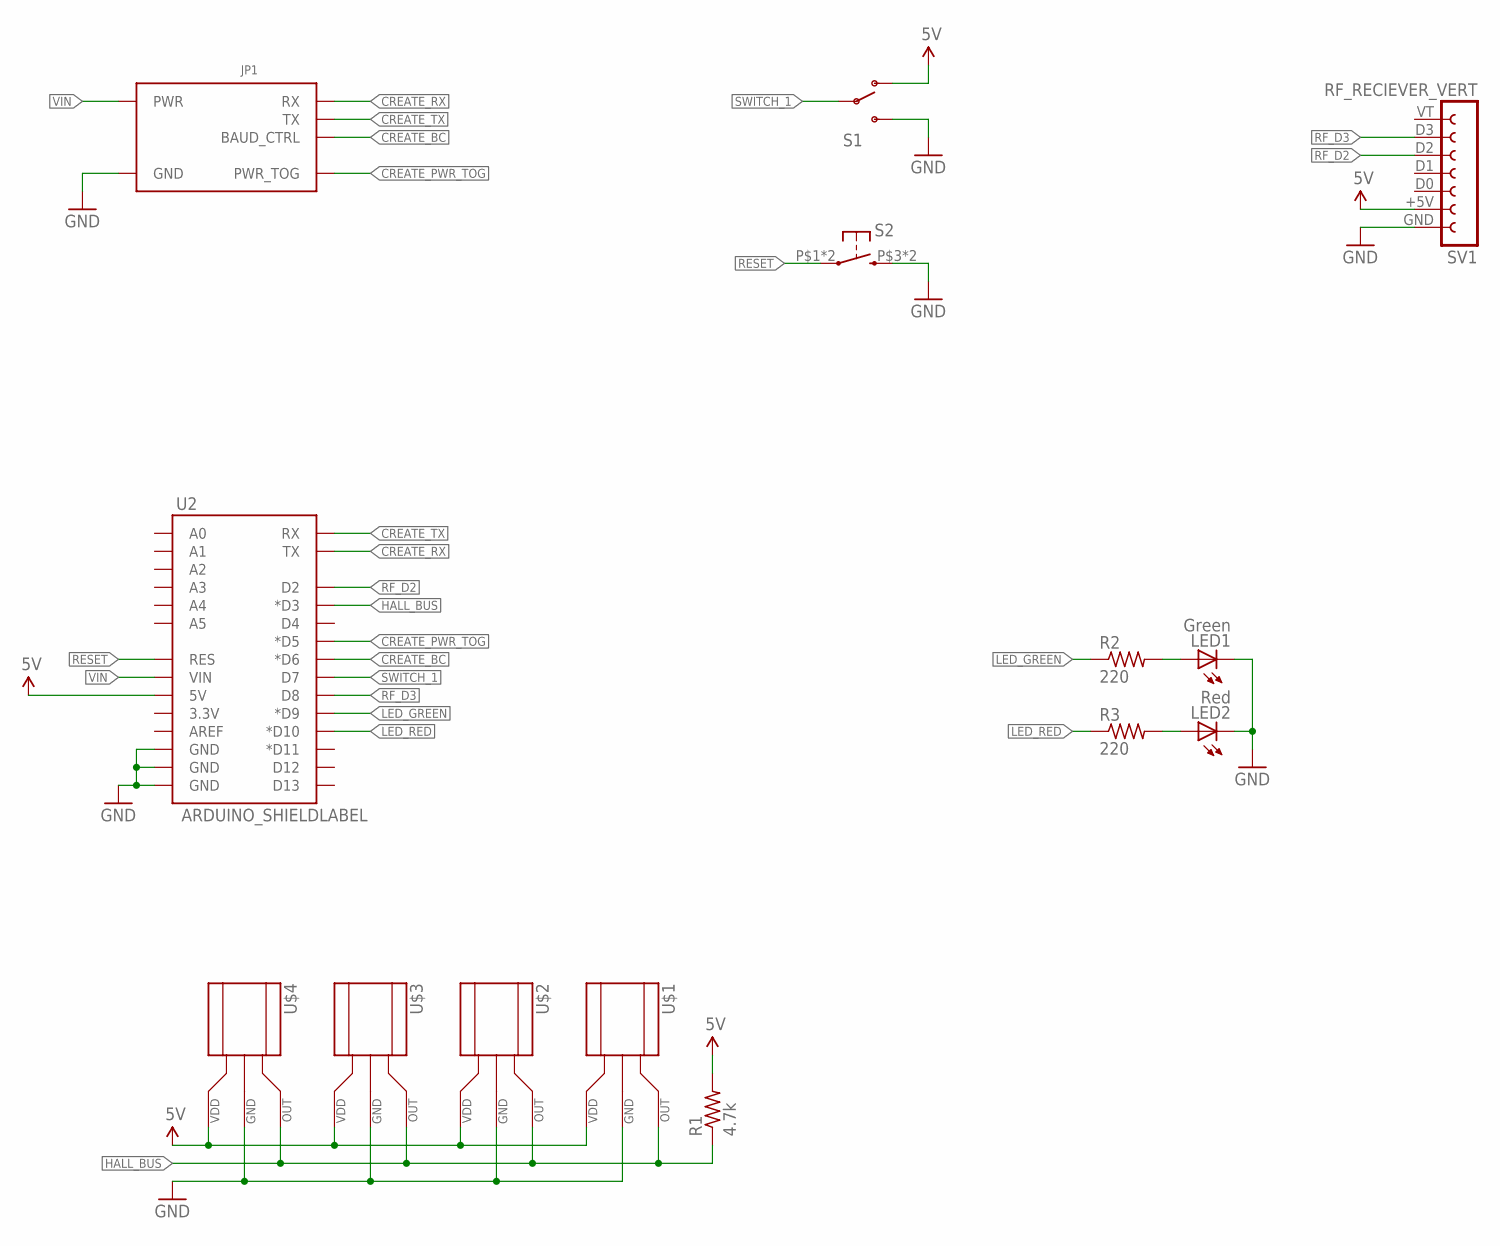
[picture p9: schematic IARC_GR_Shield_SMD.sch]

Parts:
JP1: IROBOT_CREATE_IARC_HOOKUP; 2X5-SHROUDED
LED1: Green; CHIPLED_0603
LED2: Red; CHIPLED_0603
R1: 4.7k; R0603
R2, R3: 220; R0603; DIGIKEY# P220HCT-ND
S1: SWITCH-SPDTTHRU-VERT; SWITCH-SPDT_THRU-VERT
S2: TACT_BUTTON_SMD; SIMPLE_BUTTON_SMD
SV1: RF_RECIEVER_VERT
U2: ARDUINO_SHIELDLABEL; DUEMILANOVE_SHIELD
U$1, U$2, U$3, U$4: HALL_EFFECTHEADER; 1X03

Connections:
5V: R1.2, S1.1 (O), SV1.+5V, U2.5V, U$1.1 (VDD), U$2.1 (VDD), U$3.1 (VDD), U$4.1 (VDD)
CREATE_BC: JP1.3 (BAUD_CTRL), U2.D6 (*D6)
CREATE_PWR_TOG: JP1.5 (PWR_TOG), U2.D5 (*D5)
CREATE_RX: JP1.4 (RX), U2.TX
CREATE_TX: JP1.1 (TX), U2.RX
GND: JP1.2 (GND), LED1.C, LED2.C, S1.3 (S), S2.P$3 (S), S2.P$4 (S), SV1.GND, U2.GND@0 (GND), U2.GND@1 (GND), U2.GND@2 (GND), U$1.2 (GND), U$2.2 (GND), U$3.2 (GND), U$4.2 (GND)
HALL_BUS: R1.1, U2.D3 (*D3), U$1.3 (OUT), U$2.3 (OUT), U$3.3 (OUT), U$4.3 (OUT)
LED_GREEN: R2.1, U2.D9 (*D9)
LED_RED: R3.1, U2.D10 (*D10)
unnamed: LED1.A, R2.2
unnamed: LED2.A, R3.2
RESET: S2.P$1, S2.P$2, U2.RES
RF_D2: SV1.D2, U2.D2
RF_D3: SV1.D3, U2.D8
SWITCH_1: S1.2, U2.D7
VIN: JP1.6 (PWR), U2.VIN

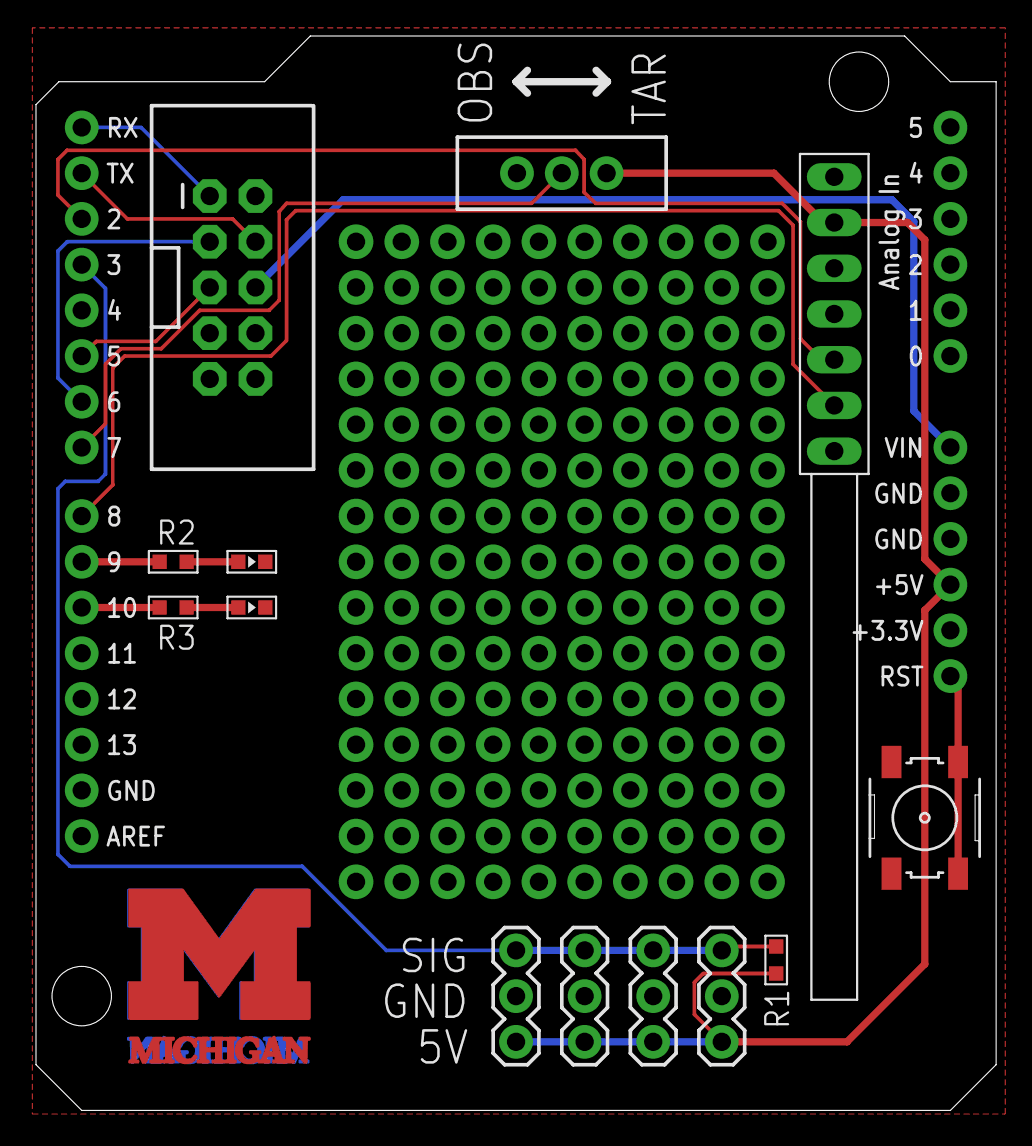
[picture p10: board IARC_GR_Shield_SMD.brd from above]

Board: 2 copper layers, 53.3 x 59.7 mm, 16 parts (1 on the bottom side), 16 nets.

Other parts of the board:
U$12, U$13: BLOCK-M-STACKED_10MM_MASK

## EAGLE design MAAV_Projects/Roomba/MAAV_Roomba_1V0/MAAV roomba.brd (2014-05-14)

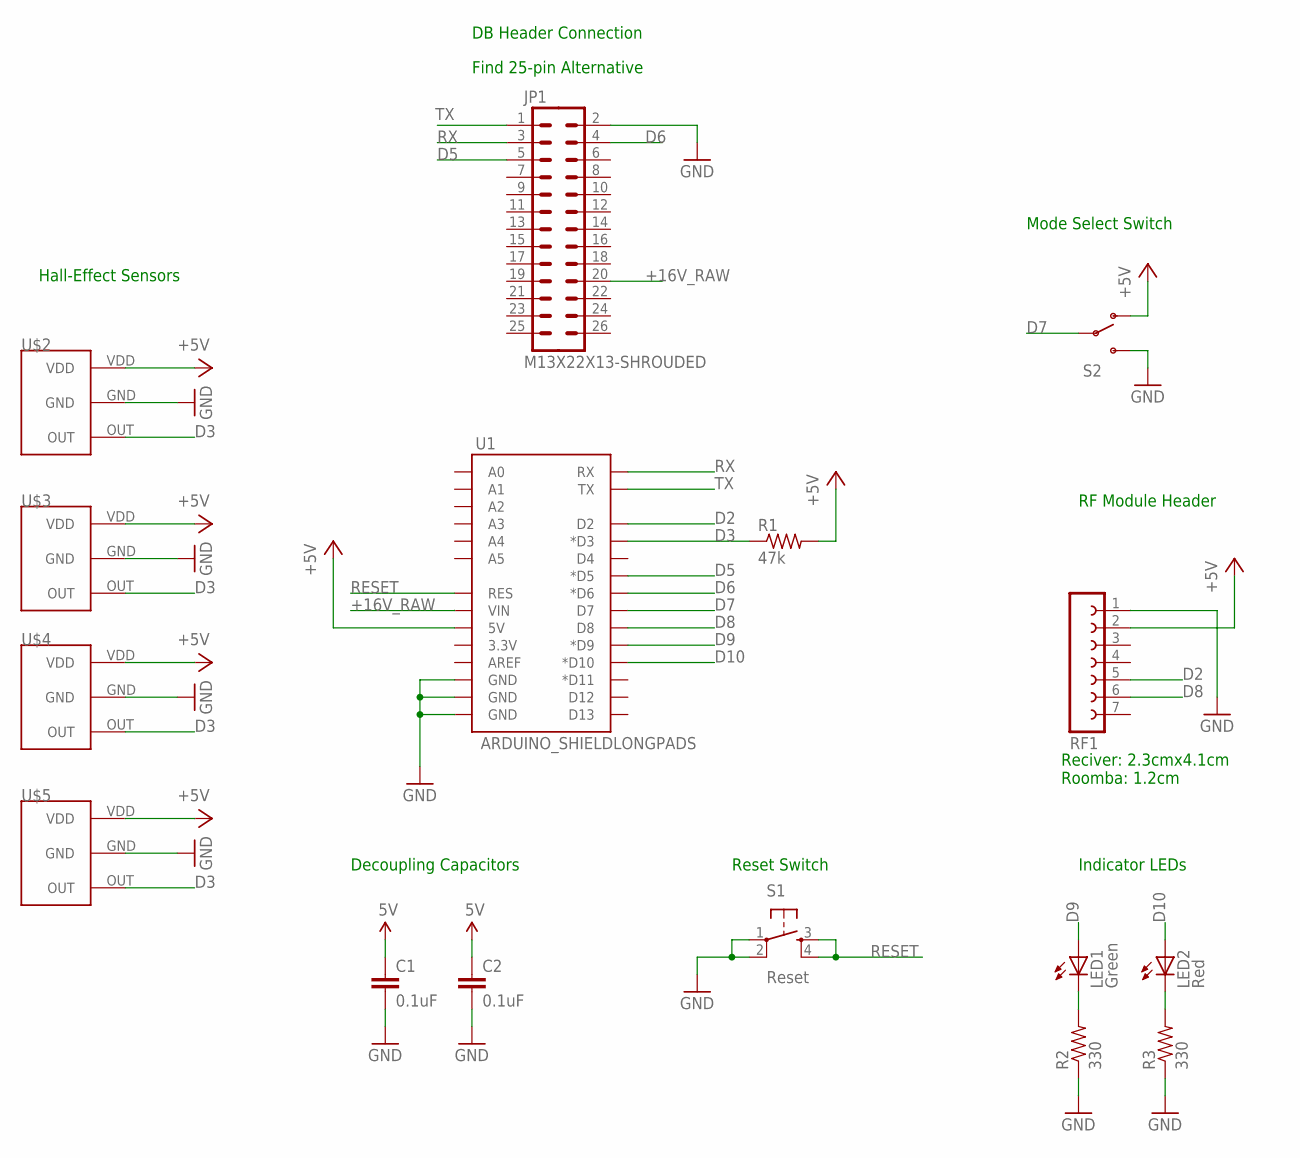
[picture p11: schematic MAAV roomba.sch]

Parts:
C1, C2: 0.1uF; CAP-PTH-SMALL2; DIGIKEY 399-4264-ND
JP1: M13X22X13-SHROUDED; 2X25-SHROUDED
LED1: Green; LED5MM; DIGIKEY 1125-1184-ND
LED2: Red; LED5MM; DIGIKEY 1125-1188-ND
R1: 47k; 0309/10; DIGIKEY CF12JT47K0
R2, R3: 330; AXIAL-0.4; DIGIKEY 330QBK-ND
RF1: FE07W; DIGIKEY S5443-ND
S1: Reset; TACTILE-PTH; DIGIKEY 450-1650-ND
S2: SWITCH-SPDTPTH; SWITCH-SPDT; DIGIKEY EG1903-ND
U1: ARDUINO_SHIELDLONGPADS; DUEMILANOVE_SHIELD_LONGPADS
U$2, U$3, U$4, U$5: HALL_EFFECT; MOUSER 621-AH180-PL-A

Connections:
5V: C1.1, C2.1, R1.2, RF1.2, S2.1 (O), U1.5V, U$2.VDD, U$3.VDD, U$4.VDD, U$5.VDD
+16V_RAW: JP1.20, U1.VIN
D2: RF1.5, U1.D2
D3: R1.1, U1.D3 (*D3), U$2.OUT, U$3.OUT, U$4.OUT, U$5.OUT
D5: JP1.5, U1.D5 (*D5)
D6: JP1.4, U1.D6 (*D6)
D7: S2.2, U1.D7
D8: RF1.6, U1.D8
D9: LED1.A, U1.D9 (*D9)
D10: LED2.A, U1.D10 (*D10)
GND: C1.2, C2.2, JP1.2, R2.P$1 (1), R3.P$1 (1), RF1.1, S1.1, S1.2, S2.3 (S), U1.GND@0 (GND), U1.GND@1 (GND), U1.GND@2 (GND), U$2.GND, U$3.GND, U$4.GND, U$5.GND
unnamed: LED1.K (C), R2.P$2 (2)
unnamed: LED2.K (C), R3.P$2 (2)
RESET: S1.3, S1.4, U1.RES
RX: JP1.3, U1.RX
TX: JP1.1, U1.TX

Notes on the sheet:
Hall-Effect Sensors
DB Header Connection
Find 25-pin Alternative
Decoupling Capacitors
Indicator LEDs
Reset Switch
Mode Select Switch
RF Module Header
Reciver: 2.3cmx4.1cm Roomba: 1.2cm

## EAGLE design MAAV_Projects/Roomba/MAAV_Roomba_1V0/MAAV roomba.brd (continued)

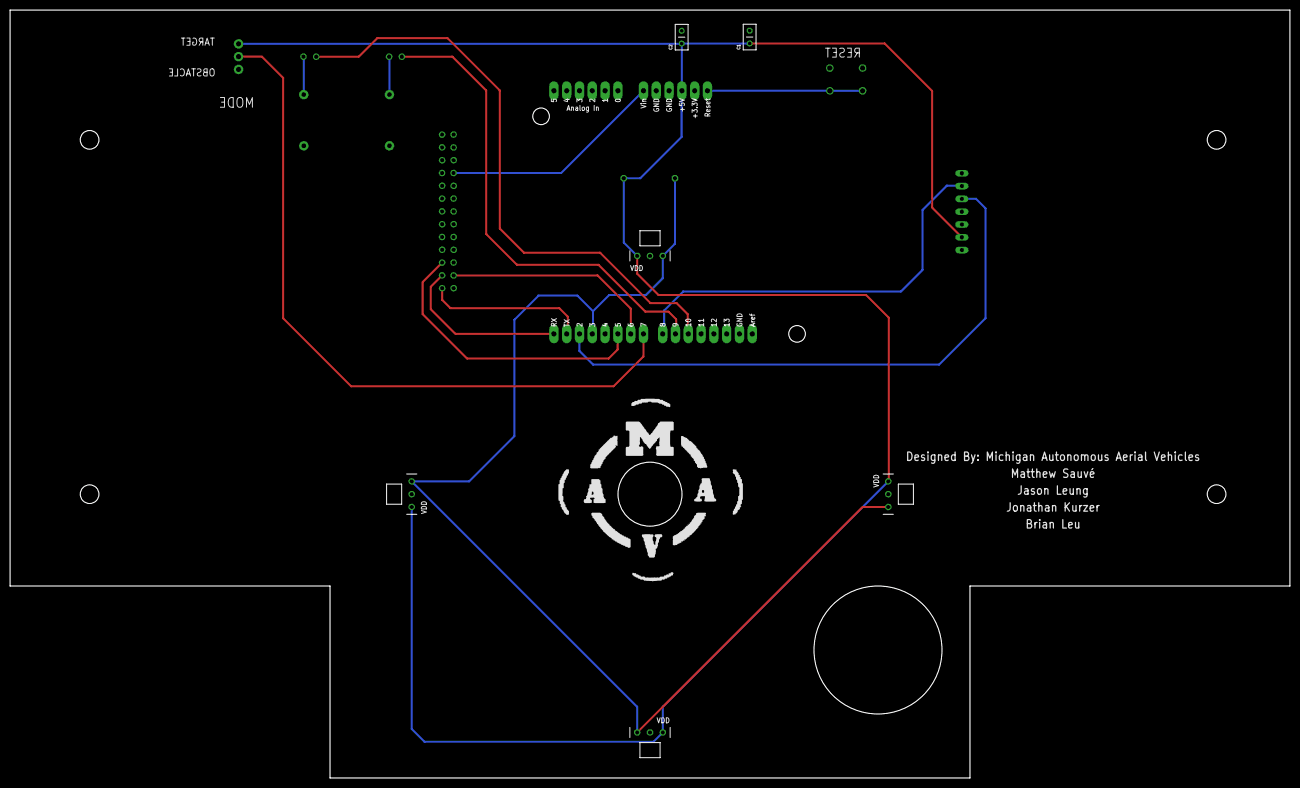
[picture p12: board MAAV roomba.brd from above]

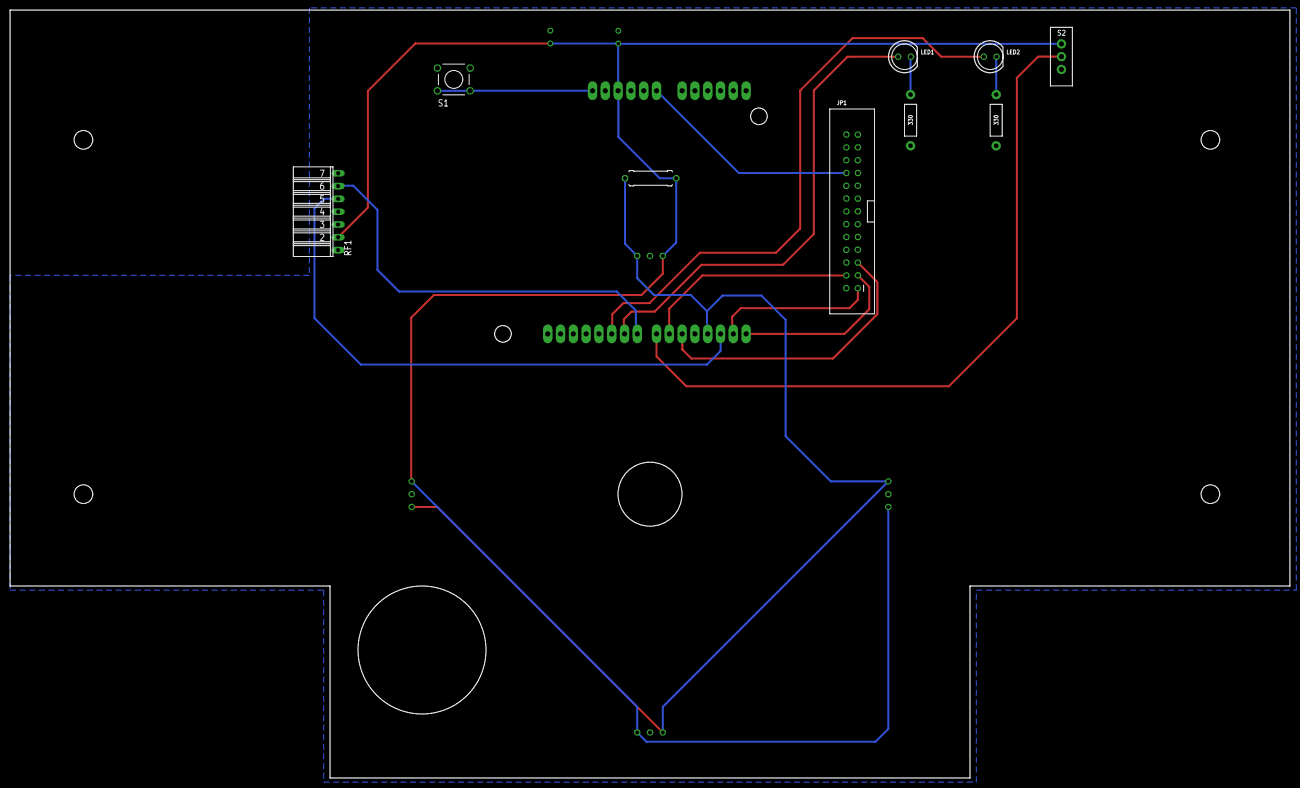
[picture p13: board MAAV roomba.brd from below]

Board: 2 copper layers, 254.0 x 152.4 mm, 18 parts (9 on the bottom side), 16 nets.

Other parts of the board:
U$1: IARC_GROUND_OUTLINE
U$6: MAAV_CIRCLE

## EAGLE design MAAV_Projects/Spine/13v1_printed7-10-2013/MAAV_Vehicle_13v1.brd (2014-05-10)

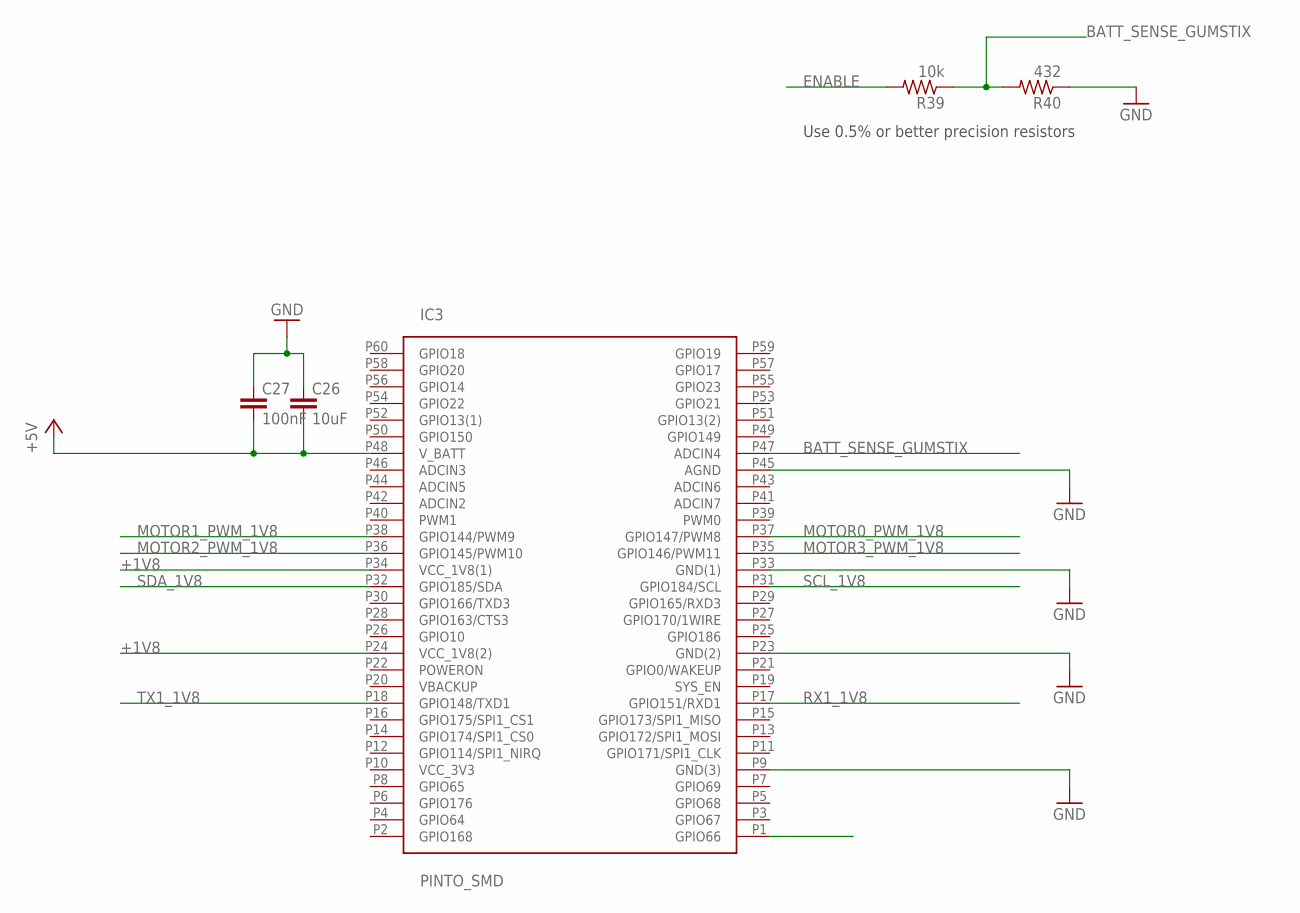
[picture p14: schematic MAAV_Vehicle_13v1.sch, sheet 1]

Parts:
C26: 10uF; C1206; DIGIKEY# 587-2399-1-ND
C27: 100nF; C0603; DIGIKEY# 1276-1000-1-ND
IC3: PINTO_SMD; DIGIKEY# S5641-ND (6)
R39: 10k; R0603; DIGIKEY# P10KDBCT-ND
R40: 432; R0603; DIGIKEY# P432DBCT-ND

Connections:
+1V8: IC3.P24 (VCC_1V8(2)), IC3.P34 (VCC_1V8(1)); also elsewhere on the board
+5V: C26.2, C27.2, IC3.P48 (V_BATT); also elsewhere on the board
BATT_SENSE_GUMSTIX: IC3.P47 (ADCIN4), R39.1, R40.2
ENABLE: R39.2; also elsewhere on the board
GND: C26.1, C27.1, IC3.P9 (GND(3)), IC3.P23 (GND(2)), IC3.P33 (GND(1)), IC3.P45 (AGND), R40.1; also elsewhere on the board
MOTOR0_PWM_1V8: IC3.P37 (GPIO147/PWM8); also elsewhere on the board
MOTOR1_PWM_1V8: IC3.P38 (GPIO144/PWM9); also elsewhere on the board
MOTOR2_PWM_1V8: IC3.P36 (GPIO145/PWM10); also elsewhere on the board
MOTOR3_PWM_1V8: IC3.P35 (GPIO146/PWM11); also elsewhere on the board
RX1_1V8: IC3.P17 (GPIO151/RXD1); also elsewhere on the board
SCL_1V8: IC3.P31 (GPIO184/SCL); also elsewhere on the board
SDA_1V8: IC3.P32 (GPIO185/SDA); also elsewhere on the board
TX1_1V8: IC3.P18 (GPIO148/TXD1); also elsewhere on the board

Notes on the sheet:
Use 0.5% or better precision resistors


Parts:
R1, R2, R9, R10, R13, R15, R17, R19: 10k; R0603; DIGIKEY# P10.0KHCT-ND
R14, R16, R18, R20: 4.7k; R0603; DIGIKEY# P4.70KHCT-ND
T3, T4, T7, T8, T9, T10: MOSFET-NCHANNELSMD; SOT23-3; DIGIKEY# BSS138KCT-ND

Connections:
+1V8: R1.2, R9.2, R13.2, R15.2, R17.2, R19.2, T3.1 (G), T4.1 (G), T7.1 (G), T8.1 (G), T9.1 (G), T10.1 (G); also elsewhere on the board
+5V: R2.2, R10.2, R14.2, R16.2, R18.2, R20.2; also elsewhere on the board
MOTOR0_PWM_1V8: R19.1, T10.2 (S); also elsewhere on the board
MOTOR1_PWM_1V8: R13.1, T7.2 (S); also elsewhere on the board
MOTOR2_PWM_1V8: R15.1, T8.2 (S); also elsewhere on the board
MOTOR3_PWM_1V8: R17.1, T9.2 (S); also elsewhere on the board
PWM_5V_M0: R20.1, T10.3 (D); also elsewhere on the board
PWM_5V_M1: R14.1, T7.3 (D); also elsewhere on the board
PWM_5V_M2: R16.1, T8.3 (D); also elsewhere on the board
PWM_5V_M3: R18.1, T9.3 (D); also elsewhere on the board
SCL_1V8: R1.1, T3.2 (S); also elsewhere on the board
SCL_5V: R2.1, T3.3 (D); also elsewhere on the board
SDA_1V8: R9.1, T4.2 (S); also elsewhere on the board
SDA_5V: R10.1, T4.3 (D); also elsewhere on the board


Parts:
C8, C9: 10uF; C1206; DIGIKEY# 587-2399-1-ND
C10, C11, C12, C13: 100nF; C0603; DIGIKEY# 1276-1000-1-ND
C14, C15: 22pF; C0603; DIGIKEY# 478-6200-1-ND
LED1, LED2, LED3: GREEN; CHIPLED_0603; DIGIKEY# 1080-1405-1-ND
Q1: CRYSTAL_16MHZ_SMD; 4-SMD_DFN
R5, R8: 1k; R0603; DIGIKEY# P1.00KHCT-ND
R7, R21: 10k; R0603; DIGIKEY# P10.0KHCT-ND
R44, R47, R48: 750; R0805; DIGIKEY# P750CCT-ND
R51: 10k; R0603; DIGIKEY# P10KDBCT-ND
R52: 432; R0603; DIGIKEY# P432DBCT-ND
S2: SWITCH-OFF-MOM; DIGIKEY# P11084SCT-ND
SV1: MA04-1
SV2: AVRISP-63X2_SMD; AVRISP-6-SMD
SV3, SV4: MA03-1; DIGIKEY# 3M9477-ND
T11: MOSFET-NCHANNELSMD; SOT23-3; DIGIKEY# BSS138KCT-ND
U3: ATMEGA328-AU; 32-TQFP; DIGIKEY# ATMEGA328-AU-ND
U4: REG_3V_8SOIC; 8-SOIC; DIGIKEY# 296-2719-5-ND

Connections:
+3V3: C8.1, U4.P$7 (OUT), U4.P$8 (OUT2)
+5V: C9.1, C10.1, C11.1, C13.1, R7.2, SV1.2, SV2.VCC, SV3.2, SV4.2, U3.P$4 (VCC), U3.P$6 (VCC2), U3.P$18 (AVCC), U4.P$5 (IN), U4.P$6 (IN2); also elsewhere on the board
BATT_SENSE: R51.1, R52.2, U3.P$19 (ADC6)
BURN_1: U3.P$9 ((T1)PD5); also elsewhere on the board
ENABLE: R8.2, R51.2; also elsewhere on the board
GND: C8.2, C9.2, C10.2, C11.2, C12.2, C13.2, C14.1, C15.1, LED1.C, LED2.C, LED3.C, R21.1, R52.1, S2.P$2 (P2), S2.P$4 (P4), SV1.1, SV2.GND, SV3.1, SV4.1, T11.2 (S), U3.P$3 (GND), U3.P$5 (GND2), U3.P$21 (AGND), U4.P$3 (GND), U4.P$4 (/EN); also elsewhere on the board
KILL_SIG: SV3.3, U3.P$23 ((ADC0)PC0)
LED1: R48.2, U3.P$13 ((OC1)PB1)
LED2: R47.2, U3.P$12 ((ICP)PB0)
LED3: R44.2, U3.P$2 ((T0)PD4)
MISO: SV2.MISO, U3.P$16 ((MISO)PB4)
MOSI: SV2.MOSI, U3.P$15 ((MOSI)PB3)
MOTOR_ENABLE: R5.2, R8.1; also elsewhere on the board
MOTOR_LOGIC: R21.2, T11.1 (G), U3.P$11 ((AIN1)PD7)
unnamed: LED1.A, R44.1
unnamed: C12.1, U3.P$20 (AREF)
unnamed: C14.2, Q1.X2, U3.P$8 (XTAL2)
unnamed: R5.1, T11.3 (D)
unnamed: C15.2, Q1.X1, U3.P$7 (XTAL1)
unnamed: LED2.A, R47.1
unnamed: LED3.A, R48.1
RESET: R7.1, S2.P$1 (P1), S2.P$3 (P3), SV2.RESET, U3.P$29 (RESET)
SCK: SV2.SCK, U3.P$17 ((SCK)PB5)
SCL_5V: SV1.4, U3.P$28 ((ADC5)PC5); also elsewhere on the board
SDA_5V: SV1.3, U3.P$27 ((ADC4)PC4); also elsewhere on the board
SERVO_1: SV4.3, U3.P$1 ((INT1)PD3)

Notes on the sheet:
Use 0.5% or better precision resistors


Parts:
C2: 330uF; C_2917_POL; DIGIKEY# 478-1811-1-ND
C3, C6, C16: 0.01uF; C0603; DIGIKEY# 490-1512-1-ND
C4, C5, C7, C25: 10uF; C1206; DIGIKEY# 587-2399-1-ND
C42, C43: 470uF; EH22-9; DIGIEKY# P14440-ND
J9: POWER_CONN
Q2: MOSFET-NCHANNELSMD; SOT23-3; DIGIKEY# BSS84CT-ND
Q3: P-MOSFET-SO8POWER-PAK; SO-8_POWER-PAK; DIGIKEY# SI7135DP-T1-GE3CT-ND
R3, R26: 10k; R0603; DIGIKEY# P10.0KHCT-ND
R11: 10k; R0603; DIGIKEY# P10KDBCT-ND
R12: 3.16k; R0603; DIGIKEY# 311-3.16KDCT-ND
U2: TPS5450; DIGIKEY# 296-23750-1-ND
U$1: INDUCTOR; CDRH127; DIGIEKY# 308-1333-1-ND
U$2: SWITCH_DPDT; SWITCH_VERT_DPDT
U$9: DIODE-SCHOTTKYBIG; DO-214AB,SMC
U$12: POWER_HOLES
U$13: BATTERY50A; LIPO_POWER_50A

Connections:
+5V: C2.A (ANODE), C7.1, C16.1, R11.2, U$1.P2 (2), U$12.P$1 (P1); also elsewhere on the board
+12V: J9.P1, Q3.D1, Q3.D2 (D1), Q3.D3 (D1), Q3.D4 (D1), Q3.D5 (D1); also elsewhere on the board
ENABLE: Q2.1 (G), R26.2, U$2.P$5; also elsewhere on the board
GND: C2.C (CATHODE), C3.2, C4.2, C5.2, C7.2, C16.2, C25.2, C42.G (CATHODE), C43.G (CATHODE), J9.P2, Q2.2 (S), R12.2, R26.1, U2.P$6 (GND), U2.P$9 (PGND), U2.P$10, U2.P$11, U2.P$12, U2.P$13, U$2.P$1, U$2.P$4, U$9.A, U$12.P$2 (P2), U$13.GND; also elsewhere on the board
unnamed: R11.1, R12.1, U2.P$4 (VSNS)
unnamed: C6.1, U2.P$1 (BOOT)
unnamed: U2.P$5 (ENA), U$2.P$2
unnamed: Q2.3 (D), Q3.G, R3.1
unnamed: C6.2, U2.P$8 (PH), U$1.P1 (1), U$9.C
V_BATT: C3.1, C4.1, C5.1, C25.1, C42.P (ANODE), C43.P (ANODE), Q3.S1, Q3.S2 (S1), Q3.S3 (S1), R3.2, U2.P$7 (VIN), U$2.P$6, U$13.BATT; also elsewhere on the board

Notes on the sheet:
Value of polarized cap depends on power requirements
10uF cap not spec-ed, but definitely helps power stability
1 of the 10uF caps near battery connector
the other near the switcher
use 1% or better precision resistors


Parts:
LED_M0, LED_M1, LED_M2, LED_M3: GREEN; CHIPLED_0805
Q4, Q5, Q6, Q7: P-MOSFET-SO8POWER-PAK; SO-8_POWER-PAK
R6, R22, R23, R24: 750; R0805; DIGIKEY# P750CCT-ND
SJ1, SJ2, SJ5, SJ7: SOLDERJUMPERNO; SJ_2S-NO
SJ3, SJ4, SJ6, SJ8: SOLDERJUMPER_2WAYS; SJ_3
U$3, U$4, U$5, U$6: ESC_CONN

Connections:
GND: LED_M0.C, LED_M1.C, LED_M2.C, LED_M3.C, U$3.GND, U$4.GND, U$5.GND, U$6.GND; also elsewhere on the board
MOTOR_ENABLE: Q4.G, Q5.G, Q6.G, Q7.G; also elsewhere on the board
unnamed: Q4.D1, Q4.D2 (D1), Q4.D3 (D1), Q4.D4 (D1), Q4.D5 (D1), R24.2, U$3.BATT
unnamed: SJ2.2, U$3.SDA/C+
unnamed: SJ3.2, U$3.SCL/C-
unnamed: LED_M0.A, R24.1
unnamed: Q5.D1, Q5.D2 (D1), Q5.D3 (D1), Q5.D4 (D1), Q5.D5 (D1), R6.2, U$4.BATT
unnamed: LED_M1.A, R6.1
unnamed: SJ1.2, U$4.SDA/C+
unnamed: SJ4.2, U$4.SCL/C-
unnamed: Q6.D1, Q6.D2 (D1), Q6.D3 (D1), Q6.D4 (D1), Q6.D5 (D1), R22.2, U$5.BATT
unnamed: LED_M2.A, R22.1
unnamed: SJ5.2, U$5.SDA/C+
unnamed: SJ6.2, U$5.SCL/C-
unnamed: Q7.D1, Q7.D2 (D1), Q7.D3 (D1), Q7.D4 (D1), Q7.D5 (D1), R23.2, U$6.BATT
unnamed: LED_M3.A, R23.1
unnamed: SJ7.2, U$6.SDA/C+
unnamed: SJ8.2, U$6.SCL/C-
PWM_5V_M0: SJ3.1; also elsewhere on the board
PWM_5V_M1: SJ4.1; also elsewhere on the board
PWM_5V_M2: SJ6.1; also elsewhere on the board
PWM_5V_M3: SJ8.1; also elsewhere on the board
SCL_5V: SJ3.3, SJ4.3, SJ6.3, SJ8.3; also elsewhere on the board
SDA_5V: SJ1.1, SJ2.1, SJ5.1, SJ7.1; also elsewhere on the board
V_BATT: Q4.S1, Q4.S2 (S1), Q4.S3 (S1), Q5.S1, Q5.S2 (S1), Q5.S3 (S1), Q6.S1, Q6.S2 (S1), Q6.S3 (S1), Q7.S1, Q7.S2 (S1), Q7.S3 (S1); also elsewhere on the board


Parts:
C1: 33pF; C0402; DIGIKEY# box
C17: 4700pf; C0402; DIGIKEY# box
C18: 1uF; C0603; DIGIKEY# 587-2984-1-ND
C19, C20, C31: 10uF; C1206; DIGIKEY# 587-2399-1-ND
C21: 0.1uF; C0603; DIGIKEY# 1276-1000-1-ND
C22: 270pF; C0402; DIGIKEY# box
C23: 150uF DNP; C2917
C24, C30, C33, C34, C35, C36: 22uF; C1206; DIGIKEY# 587-3246-1-ND
C32: 0.1uF; C0402; DIGIKEY# box
D1: PDS760; DIGIKEY# PDS760DICT-ND
L2: 10uH; DRQ125
Q8: STL60N3LLH5; POWERFLAT-8
R4: 100; R0402; DIGIKEY# box
R27, R31: 20k; R0402; DIGIKEY# box
R28: 64.9k; R0402; DIGIKEY# P64.9KDCCT-ND
R29: 10k; R0402; DIGIKEY# box
R30: 1k; R0402; DIGIKEY# box
R32: 50; R0402; DIGIKEY# box
R33: 2.32k; R0402; DIGIKEY# P2.32KDCCT-ND
R34: 27.4k; R0402; DIGIKEY# box
R35: 0.05; R2512; DIGIKEY# MCS3264R050FERCT-ND
U1: LM5022; MSOP-10

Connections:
+12V: C23.+, C24.1, C30.1, C33.1, C34.1, C35.1, C36.1, D1.C (CATHODE), R32.2; also elsewhere on the board
COMP: C1.1, C17.1, U1.P$3 (COMP)
CS: C22.1, R30.1, U1.P$8 (CS)
FB2: C1.2, R27.2, R31.1, R33.2, U1.P$2 (FB)
GND: C18.2, C19.2, C20.2, C21.2, C22.2, C23.-, C24.2, C30.2, C32.2, C33.2, C34.2, C35.2, C36.2, L2.2, R29.1, R33.1, R34.1, R35.1, U1.P$6 (GND); also elsewhere on the board
unnamed: C17.2, R27.1
unnamed: Q8.P$4 (G), R4.2
unnamed: C31.2, D1.A1 (ANODE), D1.A2 (ANODE), L2.4
unnamed: R31.2, R32.1
OUT: R4.1, U1.P$5 (OUT)
Q3_D: C31.1, L2.3, Q8.P$5 (D)
Q3_S: Q8.P$1 (S), Q8.P$2 (S), Q8.P$3 (S), R30.2, R35.2
RT: R34.2, U1.P$9 (RT)
SS2: C32.1, U1.P$10 (SS)
UVLO: R28.1, R29.2, U1.P$7 (UVLO)
VCC2: C18.1, U1.P$4 (VCC)
V_BATT: C19.1, C20.1, C21.1, L2.1, R28.2, U1.P$1 (VIN); also elsewhere on the board


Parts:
C37, C41: 0.1uF; C0603; DIGIKEY# 490-1524-1-ND
C38, C39, C40: 0.47uF; C0805; DIGIKEY# 1276-2966-1-ND
J7: MA04-1; MA-04-SMD
R25, R36, R37, R38: 10k; R0603; DIGIKEY# P10.0KHCT-ND
T1, T2: MOSFET-NCHANNELSMD; SOT23-3; DIGIKEY# BSS138KCT-ND
U$11: MAX3221-RS232; 16-TSSOP; DIGIKEY# 296-19825-1-ND

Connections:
+1V8: R25.2, R37.2, T1.1 (G), T2.1 (G); also elsewhere on the board
+5V: C39.1, C41.2, J7.1, R36.2, R38.2, U$11.P$15 (VCC), U$11.P$16 (FORCEOFF); also elsewhere on the board
GND: C40.1, C41.1, J7.4, U$11.P$1 (EN), U$11.P$12 (FORCEON), U$11.P$14 (GND); also elsewhere on the board
unnamed: C37.1, U$11.P$2 (C1+)
unnamed: C37.2, U$11.P$4 (C1-)
unnamed: C38.1, U$11.P$5 (C2+)
unnamed: C38.2, U$11.P$6 (C2-)
unnamed: C39.2, U$11.P$3 (V+)
unnamed: C40.2, U$11.P$7 (V-)
RS-232_RX1: J7.3, U$11.P$8 (RIN)
RS-232_TX1: J7.2, U$11.P$13 (DOUT)
RX1_1V8: R25.1, T1.2 (S); also elsewhere on the board
RX1_5V: R36.1, T1.3 (D), U$11.P$9 (ROUT)
TX1_1V8: R37.1, T2.2 (S); also elsewhere on the board
TX1_5V: R38.1, T2.3 (D), U$11.P$11 (DIN)


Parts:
R41: R-USR1206; R1206; DIGIKEY# P100FCT-ND, P68.1FCT-ND, P200FCT-ND
U$10: TRANSISTOR_NPN_DPAK; DPAK; DIGIKEY# 497-12849-1-ND
U$14: M02_SCREW_0.1; SCREW_TERM_2POS
U$15: MOSFET-PCHANNEL_SOT23-3; SOT23-3; DIGIKEY# BSS84CT-ND

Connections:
+5V: U$15.3 (D); also elsewhere on the board
BURN_1: U$15.1 (G); also elsewhere on the board
GND: U$10.3 (E); also elsewhere on the board
unnamed: U$10.TAB (C), U$14.P$2 (4)
unnamed: R41.2, U$15.2 (S)
unnamed: R41.1, U$10.1 (B)
V_BATT: U$14.P$1 (3); also elsewhere on the board



Board: 4 copper layers, 100.0 x 100.0 mm, 149 parts (3 on the bottom side), 90 nets.

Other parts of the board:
U$7, U$16: BLOCK-M-10MMW
U$8: IMU

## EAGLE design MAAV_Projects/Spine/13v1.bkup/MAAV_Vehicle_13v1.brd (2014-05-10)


Board: 4 copper layers, 100.0 x 100.0 mm, 104 parts (1 on the bottom side), 60 nets.

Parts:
C2: C_2917_POL
C3, C6, C16: 0.01uF; C0603
C4, C5, C7, C18, C25: 10uF; C1206
C8: 10uF; 0805
C9: 10uF; 0603-CAP
C10, C11, C12, C13: 100nF; 0603-CAP
C14, C15: 22pF; 0603-CAP
C17: 0.1uF; C0603
C28, C29: 680uF; EH22-9
IC1: PINTO_SMD
IMU_LAYOUT: IMU
J1: MA03-2
J7: MA04-1; MA-04-SMD
LASER_POWER: POWER_CONN
LED1, LED2, LED3: GREEN; LED-0603
MOTOR0, MOTOR1, MOTOR2, MOTOR3: GREEN; CHIPLED_0603
MR1: SOT-23
Q1: CRYSTAL_16MHZ
Q2, Q4, Q5, Q6, Q7: SO-8_POWER-PAK
Q3: MOSFET-NCHANNELSMD; SOT23-3
R1, R2, R9, R10, R11, R13, R15, R17, R19, R22, R26: 10k; R0603
R3, R5: 1k; R0603
R4, R6, R21, R24: 750; R0805
R7: 10k; 0603-RES
R8, R23: 10k; 0805
R12: 3.16k; R0603
R14, R16, R18, R20: 4.7k; R0603
R25, R27: 432; R0603
R44, R47, R48: 240; 0603-RES
S2: SWITCH-OFF-MOM
SJ1, SJ2, SJ3, SJ4: SJ_3
SV1: MA04-1
T3, T4, T7, T8, T9, T10: MOSFET-NCHANNELSMD; SOT23-3
T11: SOT-23
U2: TPS5450
U3: ATMEGA328-AU; 32-TQFP
U4: REG_3V_8SOIC; 8-SOIC
U$1: INDUCTOR; CDRH127
U$2: SWITCH_DPDT; SWITCH_VERT_DPDT
U$3, U$5, U$13, U$14: ESC_CONN
U$4, U$6, U$15, U$18: DIODE-SCHOTTKY; DO-214AC,SMC
U$7: TM4C123GH6PM; 64-PQFP
U$8: LIPO_POWER
U$9: BATTERY50A; LIPO_POWER_50A
U$10, U$16, U$17: H3894-ND
U$11: DIODE-SCHOTTKYBIG; DO-214AB,SMC
U$12: POWER_HOLES

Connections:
+1V8: IC1.P24, IC1.P34, R1.2, R9.2, R13.2, R15.2, R17.2, R19.2, T3.1, T4.1, T7.1, T8.1, T9.1, T10.1
+5V: C2.A, C7.1, C9.1, C10.1, C11.1, C13.1, C16.1, C17.2, C18.2, IC1.P48, J1.P$6, J7.1, R2.2, R7.2, R10.2, R11.2, R14.2, R16.2, R18.2, R20.2, SV1.2, U3.P$4, U3.P$6, U3.P$18, U4.P$5, U4.P$6, U$1.P2, U$10.POW, U$12.P$1, U$16.POW, U$17.POW
+12V: C3.1, C4.1, C5.1, C25.1, C28.+, C29.+, Q2.S1, Q2.S2, Q2.S3, Q4.S1, Q4.S2, Q4.S3, Q5.S1, Q5.S2, Q5.S3, Q6.S1, Q6.S2, Q6.S3, Q7.S1, Q7.S2, Q7.S3, R3.2, R8.2, U2.P$7, U$2.P$3, U$9.BATT
-3V3: C8.1, U4.P$7, U4.P$8
BATT_SENSE: R26.1, R27.2, U3.P$19
ENABLE: MR1.2, Q3.1, R22.2, R26.2, U$2.P$2
GND: C2.C, C3.2, C4.2, C5.2, C7.2, C8.2, C9.2, C10.2, C11.2, C12.2, C13.2, C14.1, C15.1, C16.2, C17.1, C18.1, C25.2, C28.-, C29.-, IC1.P9, IC1.P23, IC1.P33, IC1.P45, J1.P$4, J7.4, LASER_POWER.P2, LED1.C, LED2.C, LED3.C, MOTOR0.C, MOTOR1.C, MOTOR2.C, MOTOR3.C, Q3.2, R12.2, R23.1, R25.1, R27.1, S2.P$2, S2.P$4, SV1.1, T11.2, U2.P$6, U2.P$9, U2.P$10, U2.P$11, U2.P$12, U2.P$13, U3.P$3, U3.P$5, U3.P$21, U4.P$3, U4.P$4, U$2.P$1, U$2.P$4, U$3.GND, U$4.A, U$5.GND, U$6.A, U$7.P$12, U$7.P$27, U$7.P$39, U$7.P$55, U$9.GND, U$10.GND, U$11.A, U$12.P$2, U$13.GND, U$14.GND, U$15.A, U$16.GND, U$17.GND, U$18.A
KILL_SIG: U3.P$12, U$17.SIG
LED1: R48.2, U3.P$13
LED2: R47.2, U3.P$26
LED3: R44.2, U3.P$2
M0_POWER: Q2.D1, Q2.D2, Q2.D3, Q2.D4, Q2.D5, R21.2, U$13.BATT, U$18.C
M1_POWER: Q6.D1, Q6.D2, Q6.D3, Q6.D4, Q6.D5, R24.2, U$5.BATT, U$6.C
M2_POWER: Q5.D1, Q5.D2, Q5.D3, Q5.D4, Q5.D5, R4.2, U$3.BATT, U$4.C
M3_POWER: Q7.D1, Q7.D2, Q7.D3, Q7.D4, Q7.D5, R6.2, U$14.BATT, U$15.C
MISO: J1.P$1, U3.P$16
MOSI: J1.P$5, U3.P$15
MOTOR0_PWM_1V8: IC1.P38, R13.1, T7.2
MOTOR0_PWM_5V: R14.1, SJ1.3, T7.3
MOTOR1_PWM_1V8: IC1.P36, R15.1, T8.2
MOTOR1_PWM_5V: R16.1, SJ3.3, T8.3
MOTOR2_PWM_1V8: IC1.P35, R17.1, T9.2
MOTOR2_PWM_5V: R18.1, SJ2.3, T9.3
MOTOR3_PWM_1V8: IC1.P37, R19.1, T10.2
MOTOR3_PWM_5V: R20.1, SJ4.3, T10.3
MOTOR_ENABLE: MR1.1, Q2.G, Q5.G, Q6.G, Q7.G, R23.2
MOTOR_LOGIC: T11.3, U3.P$11
unnamed: Q4.G, R3.1, R5.2
unnamed: LED1.A, R44.1
unnamed: C12.1, U3.P$20
unnamed: R11.1, R12.1, U2.P$4
unnamed: MR1.3, R8.1, T11.1
unnamed: C14.2, Q1.P$2, U3.P$8
unnamed: C15.2, Q1.P$1, U3.P$7
unnamed: C6.1, U2.P$1
unnamed: Q3.3, R5.1
unnamed: U2.P$5, U$2.P$5, U$2.P$6
unnamed: MOTOR1.A, R24.1
unnamed: SJ1.2, U$13.SDA/C+
unnamed: MOTOR2.A, R4.1
unnamed: MOTOR3.A, R6.1
unnamed: SJ2.2, U$3.SDA/C+
unnamed: SJ3.2, U$5.SDA/C+
unnamed: SJ4.2, U$14.SDA/C+
unnamed: MOTOR0.A, R21.1
unnamed: C6.2, U2.P$8, U$1.P1, U$11.C
unnamed: LED2.A, R47.1
unnamed: LED3.A, R48.1
unnamed: LASER_POWER.P1, Q4.D1, Q4.D2, Q4.D3, Q4.D4, Q4.D5
unnamed: IC1.P47, R22.1, R25.2
OPT0_SIG: U3.P$23, U$16.SIG
OPT1_SIG: U3.P$1, U$10.SIG
RESET: J1.P$3, R7.1, S2.P$1, S2.P$3, U3.P$29
RXD1: IC1.P17, J7.3
SCK: J1.P$2, U3.P$17
SCL_1V8: IC1.P31, R1.1, T3.2
SCL_5V: R2.1, SV1.4, T3.3, U3.P$28, U$3.SCL/C-, U$5.SCL/C-, U$13.SCL/C-, U$14.SCL/C-
SDA_1V8: IC1.P32, R9.1, T4.2
SDA_5V: R10.1, SJ1.1, SJ2.1, SJ3.1, SJ4.1, SV1.3, T4.3, U3.P$27
TXD1: IC1.P18, J7.2

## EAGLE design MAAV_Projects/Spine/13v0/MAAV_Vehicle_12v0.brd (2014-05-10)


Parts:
C26: 10uF; 0603-CAP; DIGIKEY 445-4112-1-ND
C27: 100nF; 0603-CAP; DIGIKEY 478-1239-1-ND
IC3: PINTO_SMD; DIGIKEY S5641-ND (6)
J7: MA04-1; 455-1751-1-ND
U$7: IMU

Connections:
+1V8: IC3.P34 (VCC_1V8(1)); also elsewhere on the board
+5V: C26.2, C27.2, IC3.P48 (V_BATT), J7.1; also elsewhere on the board
GND: C26.1, C27.1, IC3.P9 (GND(3)), IC3.P23 (GND(2)), IC3.P33 (GND(1)), IC3.P45 (AGND), J7.4; also elsewhere on the board
MOTOR1_PWM_1V8: IC3.P38 (GPIO144/PWM9); also elsewhere on the board
MOTOR2_PWM_1V8: IC3.P36 (GPIO145/PWM10); also elsewhere on the board
MOTOR3_PWM_1V8: IC3.P35 (GPIO146/PWM11); also elsewhere on the board
MOTOR4_PWM_1V8: IC3.P37 (GPIO147/PWM8); also elsewhere on the board
RXD1: IC3.P17 (GPIO151/RXD1), J7.3
SCL_1V8: IC3.P31 (GPIO184/SCL); also elsewhere on the board
SDA_1V8: IC3.P32 (GPIO185/SDA); also elsewhere on the board
TXD1: IC3.P18 (GPIO148/TXD1), J7.2


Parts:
R1, R2, R9, R10, R13, R15, R17, R19: 10k; 0603-RES; DIGIKEY P10KGCT-ND
R14, R16, R18, R20: 4.7k; 0603-RES; DIGIKEY P10KGCT-ND
T3, T4, T7, T8, T9, T10: NMOSSOT23; SOT-23; DIGIKEY BSS138KCT-ND

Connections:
+1V8: R1.2, R9.2, R13.2, R15.2, R17.2, R19.2, T3.3 (G), T4.3 (G), T7.3 (G), T8.3 (G), T9.3 (G), T10.3 (G); also elsewhere on the board
+5V: R2.2, R10.2, R14.2, R16.2, R18.2, R20.2; also elsewhere on the board
MOTOR1_PWM_1V8: R13.1, T7.2 (S); also elsewhere on the board
MOTOR1_PWM_5V: R14.1, T7.1 (D); also elsewhere on the board
MOTOR2_PWM_1V8: R15.1, T8.2 (S); also elsewhere on the board
MOTOR2_PWM_5V: R16.1, T8.1 (D); also elsewhere on the board
MOTOR3_PWM_1V8: R17.1, T9.2 (S); also elsewhere on the board
MOTOR3_PWM_5V: R18.1, T9.1 (D); also elsewhere on the board
MOTOR4_PWM_1V8: R19.1, T10.2 (S); also elsewhere on the board
MOTOR4_PWM_5V: R20.1, T10.1 (D); also elsewhere on the board
SCL_1V8: R1.1, T3.2 (S); also elsewhere on the board
SCL_5V: R2.1, T3.1 (D); also elsewhere on the board
SDA_1V8: R9.1, T4.2 (S); also elsewhere on the board
SDA_5V: R10.1, T4.1 (D); also elsewhere on the board


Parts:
C1: 10uF Pol; 0805; DIGIKEY 478-3273-1-ND
C8: 10uF; 0805; DIGIKEY 490-1746-1-ND
C9: 10uF; 0603-CAP; DIGIKEY 445-4112-1-ND
C10, C11, C12, C13: 100nF; 0603-CAP; DIGIKEY 478-1239-1-ND
C14, C15: 22pF; 0603-CAP; DIGIKEY 478-6200-1-ND
IC1: TRM-315-LT; TRM-XXX-LT; DIGIKEY TRM-315-LT-ND
J1: MA03-2
LED1, LED2, LED3: GREEN; LED-0603; DIGIKEY 1080-1405-1-ND
MR1: PMOSSOT23; SOT-23; DIGIKEY FDV304PCT-ND
Q1: CRYSTAL_16MHZ
R3, R4, R5, R6, R7: 10k; 0603-RES; DIGIKEY P10KGCT-ND
R8, R23: 10k; 0805; DIGIKEY P10KACT-ND
R44, R47, R48, R49, R50: 240; 0603-RES; DIGIKEY P240GCT-ND
R45: 1M-5M; 0603-RES; DIGIKEY P1.0MGCT-ND
R46: 750; 0603-RES; DIGIKEY P0.0GCT-ND
R51: 10k; 0603-RES; DIGIKEY P240GCT-ND
R52: 4.7k; 0603-RES; DIGIKEY P4.7KGCT-ND
RECEIVE: GREEN; LED-0603; DIGIKEY 1080-1405-1-ND
S2: SWITCH-OFF-MOM
SEND: RED; LED-0603; DIGIKEY 1080-1400-1-ND
SV1: MA04-1
T1, T2, T11: NMOSSOT23; SOT-23; DIGIKEY BSS138KCT-ND
U3: ATMEGA328-AU; 32-TQFP
U4: REG_3V_8SOIC; 8-SOIC
U$10, U$16: H3894-ND
U$13: ANTENNA-418MHZ

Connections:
+5V: C9.1, C10.1, C11.1, C13.1, J1.P$6, R5.2, R6.2, R7.2, RECEIVE.A, SV1.2, U3.P$4 (VCC), U3.P$6 (VCC2), U3.P$18 (AVCC), U4.P$5 (IN), U4.P$6 (IN2), U$10.POW, U$16.POW; also elsewhere on the board
+12V: R8.2; also elsewhere on the board
ANTENNA: IC1.1 (ANT), U$13.P$1; also elsewhere on the board
BATT_SENSE: R51.1, R52.2, U3.P$19 (ADC6)
DATA_3V: IC1.7 (DATA), R4.1, T2.2 (S)
DATA_5V: R5.1, T2.1 (D), U3.P$24 ((ADC1)PC1)
ENABLE: MR1.2 (S), R51.2; also elsewhere on the board
GND: C1.2, C8.2, C9.2, C10.2, C11.2, C12.2, C13.2, C14.1, C15.1, IC1.2 (GND), IC1.10 (GND), J1.P$4, LED1.C, LED2.C, LED3.C, R23.1, R52.1, S2.P$2 (P2), S2.P$4 (P4), SEND.C, SV1.1, T11.2 (S), U3.P$3 (GND), U3.P$5 (GND2), U3.P$21 (AGND), U4.P$3 (GND), U4.P$4 (/EN), U$10.GND, U$16.GND; also elsewhere on the board
INT0: U3.P$32 ((INT0)PD2); also elsewhere on the board
LED1: R48.2, U3.P$13 ((OC1)PB1)
LED2: R47.2, U3.P$12 ((ICP)PB0)
LED3: R44.2, U3.P$2 ((T0)PD4)
MISO: J1.P$1, U3.P$16 ((MISO)PB4); also elsewhere on the board
MOSI: J1.P$5, U3.P$15 ((MOSI)PB3); also elsewhere on the board
MOTOR1_RPM: U3.P$10 ((AIN0)PD6); also elsewhere on the board
MOTOR2_RPM: U3.P$9 ((T1)PD5); also elsewhere on the board
MOTOR3_RPM: U3.P$31 ((TXD)PD1); also elsewhere on the board
MOTOR4_RPM: U3.P$30 ((RXD)PD0); also elsewhere on the board
MOTOR_ENABLE: MR1.1 (D), R23.2; also elsewhere on the board
MOTOR_LOGIC: T11.3 (G), U3.P$11 ((AIN1)PD7)
unnamed: LED1.A, R44.1
unnamed: C12.1, U3.P$20 (AREF)
unnamed: MR1.3 (G), R8.1, T11.1 (D)
unnamed: C14.2, Q1.P$2, U3.P$8 (XTAL2)
unnamed: C15.2, Q1.P$1, U3.P$7 (XTAL1)
unnamed: R50.2, RECEIVE.C
unnamed: R49.1, SEND.A
unnamed: IC1.5 (AREF), R45.2
unnamed: IC1.12 (LADJ), R46.1
unnamed: LED2.A, R47.1
unnamed: LED3.A, R48.1
OPT_SIG: U3.P$23 ((ADC0)PC0), U$16.SIG
PING0: U3.P$1 ((INT1)PD3), U$10.SIG
RESET: J1.P$3, R7.1, S2.P$1 (P1), S2.P$3 (P3), U3.P$29 (RESET)
RF_SEL_3V: IC1.8 (TR_SEL), R3.1, T1.2 (S)
RF_SEL_5V: R6.1, R49.2, R50.1, T1.1 (D), U3.P$14 ((SS)PB2); also elsewhere on the board
RSSI: IC1.4 (RSSI), U3.P$26 ((ADC3)PC3)
SCK: J1.P$2, U3.P$17 ((SCK)PB5); also elsewhere on the board
SCL_5V: SV1.4, U3.P$28 ((ADC5)PC5); also elsewhere on the board
SDA_5V: SV1.3, U3.P$27 ((ADC4)PC4); also elsewhere on the board
VCC: C1.1, C8.1, IC1.9 (PDN), IC1.11 (VCC), R3.2, R4.2, R45.1, R46.2, T1.3 (G), T2.3 (G), U4.P$7 (OUT), U4.P$8 (OUT2)

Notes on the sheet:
Kill Switch


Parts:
C2: CAP_POL; 2917; DIGIKEY 478-1811-1-ND
C3, C6, C16: 0.01uF; C1210; DIGIKEY 478-1601-1-ND
C4, C5: 4.7uF; C1210; DIGIKEY 399-5777-1-ND
C7, C25: 10uF; C1210; DIGIKEY 445-1597-1-ND
C28, C29: 680uF; EH22-9; DIGIKEY P12378-ND
J9: POWER_CONN
Q2: P-MOSFET-SO8; SO-08; DIGIKEY SI4114DY-T1-GE3CT-ND
R11: 10k; R0603; DIGIKEY P10KDBCT-ND
R12: 3.16k; R0603; DIGIKEY 311-3.16KDCT-ND
R22: 4.7k; 0805; DIGIKEY P4.7KACT-ND
R53: 1k; 0805; DIGIKEY P1.0KACT-ND
S1: SWITCH-ON-ON
U2: TPS5450
U$1: CDRH127
U$2: SCHOTTKY-DIODE; DO-214AB,SMC; DIGIKEY B540C-FDICT-ND
U$8: LIPO_POWER
U$12: POWER_HOLES

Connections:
+5V: C2.2 (+), C7.1, C16.1, R11.2, U$1.P2 (2), U$12.P$1 (P1); also elsewhere on the board
+12V: C3.1, C4.1, C5.1, C25.1, C28.+, C29.+, Q2.1 (S), Q2.2 (S), Q2.3 (S), S1.P$3 (P3), U2.P$7 (VIN), U$8.V_BATT; also elsewhere on the board
ENABLE: Q2.4 (G), R22.1, S1.P$2 (P2); also elsewhere on the board
GND: C2.1 (-), C3.2, C4.2, C5.2, C7.2, C16.2, C25.2, C28.-, C29.-, J9.P2, R12.2, R53.1, S1.P$1 (P1), U2.P$6 (GND), U2.P$9 (PGND), U2.P$10, U2.P$11, U2.P$12, U2.P$13, U$2.P$1, U$8.GND, U$12.P$2 (P2); also elsewhere on the board
unnamed: R11.1, R12.1, U2.P$4 (VSNS)
unnamed: C6.1, U2.P$1 (BOOT)
unnamed: R22.2, R53.2, U2.P$5 (ENA)
unnamed: C6.2, U2.P$8 (PH), U$1.P1 (1), U$2.P$2
unnamed: J9.P1, Q2.5 (D), Q2.6 (D), Q2.7 (D), Q2.8 (D)

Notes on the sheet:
Value of polarized cap depends on power requirements
10uF cap not spec-ed, but definitely helps power stability
1 of the 10uF caps near battery connector
the other near the switcher
use 1% or better precision resistors


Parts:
J2, J3, J4, J5: MOTOR_CONNTRU_HOLE; MOTOR_CONN_THRU
MOTOR1, MOTOR2, MOTOR3, MOTOR4: GREEN; CHIPLED_0805; DIGIKEY 160-1423-1-ND
R24, R25, R26, R27: 330; 0805; DIGIKEY P330ADCT-ND
SJ1, SJ2, SJ3, SJ4: SOLDERJUMPERNO; SJ_2S-NO
T5, T6, T12, T13: MOTOR_NFET; 8-SOIC
U$3, U$4, U$5, U$6: SCHOTTKY-MOTORS; DO-214AC,SMA

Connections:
+12V: J2.+12V, J3.+12V, J4.+12V, J5.+12V, MOTOR1.A, MOTOR2.A, MOTOR3.A, MOTOR4.A, U$3.P$2, U$4.P$2, U$5.P$2, U$6.P$2; also elsewhere on the board
GND: T5.P$1 (S1), T5.P$2 (S2), T5.P$3 (S3), T6.P$1 (S1), T6.P$2 (S2), T6.P$3 (S3), T12.P$1 (S1), T12.P$2 (S2), T12.P$3 (S3), T13.P$1 (S1), T13.P$2 (S2), T13.P$3 (S3); also elsewhere on the board
MOTOR1_NEG: J2.GND, R24.1, T5.P$5 (D1), T5.P$6 (D2), T5.P$7 (D3), T5.P$8 (D4), U$3.P$1
MOTOR1_PWM_5V: SJ1.2; also elsewhere on the board
MOTOR2_NEG: J5.GND, R27.1, T13.P$5 (D1), T13.P$6 (D2), T13.P$7 (D3), T13.P$8 (D4), U$6.P$1
MOTOR2_PWM_5V: SJ4.2; also elsewhere on the board
MOTOR3_NEG: J3.GND, R26.1, T12.P$5 (D1), T12.P$6 (D2), T12.P$7 (D3), T12.P$8 (D4), U$5.P$1
MOTOR3_PWM_5V: SJ3.2; also elsewhere on the board
MOTOR4_NEG: J4.GND, R25.1, T6.P$5 (D1), T6.P$6 (D2), T6.P$7 (D3), T6.P$8 (D4), U$4.P$1
MOTOR4_PWM_5V: SJ2.2; also elsewhere on the board
MOTOR_ENABLE: T5.P$4 (G), T6.P$4 (G), T12.P$4 (G), T13.P$4 (G); also elsewhere on the board
unnamed: MOTOR1.C, R24.2
unnamed: MOTOR2.C, R25.2
unnamed: MOTOR3.C, R26.2
unnamed: MOTOR4.C, R27.2
unnamed: J2.SIG, SJ1.1
unnamed: J5.SIG, SJ4.1
unnamed: J4.SIG, SJ2.1
unnamed: J3.SIG, SJ3.1


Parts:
C17, C19, C21, C23: 10uF; 0603-CAP; DIGIKEY 445-4112-1-ND
C18, C20, C22, C24: 100nF; 0603-CAP; DIGIKEY 478-1239-1-ND
IC2: LM339D; SO14; DIGIKEY 296-1013-1-ND
R28, R30, R32, R34: 10k; 0603-RES; DIGIKEY P10KGCT-ND
R29, R31, R33, R35: 2k; 0603-RES; DIGIKEY P2.0KGCT-ND
U$9, U$11, U$14, U$15: MOTOR_SENSE

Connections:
+5V: IC2.5 (+IN), IC2.7 (+IN), IC2.9 (+IN), IC2.11 (+IN), R28.1, R30.1, R32.1, R34.1; also elsewhere on the board
+12V: IC2.3 (V+); also elsewhere on the board
GND: C18.2, C20.2, C22.2, C24.2, IC2.12 (GND); also elsewhere on the board
MOTOR1_RPM: IC2.13 (OUT); also elsewhere on the board
MOTOR1_SENSE: R29.1, U$15.SIGNAL
MOTOR2_RPM: IC2.14 (OUT); also elsewhere on the board
MOTOR2_SENSE: R31.1, U$14.SIGNAL
MOTOR3_RPM: IC2.1 (OUT); also elsewhere on the board
MOTOR3_SENSE: R33.1, U$11.SIGNAL
MOTOR4_RPM: IC2.2 (OUT); also elsewhere on the board
MOTOR4_SENSE: R35.1, U$9.SIGNAL
unnamed: C19.1, C20.1, R31.2
unnamed: C17.2, IC2.4 (-IN), R28.2
unnamed: C17.1, C18.1, R29.2
unnamed: C19.2, IC2.6 (-IN), R30.2
unnamed: C21.1, C22.1, R33.2
unnamed: C21.2, IC2.8 (-IN), R32.2
unnamed: C23.1, C24.1, R35.2
unnamed: C23.2, IC2.10 (-IN), R34.2


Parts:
R21: 10k; R0603
U$17: RF12

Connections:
+5V: R21.1, U$17.P$9 (3V3); also elsewhere on the board
ANTENNA: U$17.P$8 (ANT); also elsewhere on the board
GND: U$17.P$7 (GND), U$17.P$10 (GND2); also elsewhere on the board
INT0: U$17.P$2 (IRQ); also elsewhere on the board
MISO: U$17.P$1 (SDO); also elsewhere on the board
MOSI: U$17.P$12 (SDI); also elsewhere on the board
unnamed: R21.2, U$17.P$3 (FFS)
RF_SEL_5V: U$17.P$14 (SEL); also elsewhere on the board
SCK: U$17.P$13 (SCK); also elsewhere on the board



Board: 4 copper layers, 100.0 x 100.0 mm, 137 parts (3 on the bottom side), 84 nets.

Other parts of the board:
U$18: BLOCK-M

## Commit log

2014-05-10 added lots of files to inital commit
    [MAAV roomba.brd, MAAV roomba.sch, MAAV_Vehicle_12v0.brd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]
2014-05-14 added block-M holes layout to BlockM.lbr
2014-05-14 50mm logo and reformatted README
2014-05-14 modified .gitignore
    [MAAV Vector Logo.dxf]
2014-05-14 addes shild version of romba borard and library to match
    [MAAV roomba.brd, RoombaShildOnly.brd, RoombaShildOnly.sch]
2014-05-15 added 2014 version of spine on repo
    [Spine14_v0.sch]
2014-05-16 power management systems for Spine14v0
    [Spine14_v0.sch]
2014-05-20 changed TC2050-IDC-NL to JTAG_IDC-10. connected all IDC connector layouts to respective 6-pin and 10-pin devices
2014-05-20 fixed pad layout names for 6-pin plug_of_nails connector. should be in correct orientation
2014-05-20 added JTAG programmer for tiva and nets for ATMega
    [Spine14_v0.sch]
2014-05-21 most connections for gunstix, atmega, tiva, and power management systems. need to connect MCU's together and create motor output. consider phoenix edge lite
    [Spine14_v0.sch]
2014-05-21 fixed 50A power connector (molex?) and added tiva c series to library
2014-05-22 adding px4 connector header
2014-05-22 worked on schematic.. shifted sheets around for 13v1
    [MAAV_Vehicle_13v1.sch, Spine14_v0.sch]
2014-05-22 added last semester's work on separate modules as reference
    [Logic_Level_Bidirectional.sch, Motor Ouptut.sch, power supply.sch]
2014-05-22 organized components and implemented i2c bus. next is motors
    [Spine14_v0.sch]
2014-05-22 too tired. will finish motors later
    [Spine14_v0.sch]
2014-05-23 most level shifters, and most of motor output. only main things left are SD card and IMU
    [Spine14_v0.sch]
2014-05-23 pushing again
    [Spine14_v0.sch]
2014-05-23 changed motor output to 3v3 logic. going to add switches, SD card, and IMU, then i should be finished with schematic
    [Spine14_v0.sch]
2014-05-23 added Ti-power module to MAAV.lbr
2014-05-24 just need to add switches and IMU and should be done with all the essentials... time to move on to the KNIGHT RIDERRRR. also working on a 4PDT switch
    [Spine14_v0.sch]
2014-05-24 got rid of 4PDT device. kept symbol
2014-05-29 moved some files around and added SMD version of roomba shiled
    [MAAV roomba.brd, MAAV roomba.sch, MAAV_RoombaShieldOnly_2V0.brd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]
2014-06-08 modidified roomba shield
    [MAAV_RoombaShieldOnly_2V0.brd, MAAV_RoombaShieldOnly_2V0.sch, RoombaShieldOnly.brd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]
2014-07-08 added the two roomba varients
    [IARC_GR_Shield.brd, IARC_GR_Shield.sch, IARC_GR_Shield_SMD.brd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]
2014-07-09 started work on Spine 14v1. for the DJI (no gumstix)
    [Spine14v1.brd, Spine14v1.sch]
2014-07-09 updated dims and holes. added roundovers to hard corners of baord. added a drawing of the body that the board mounts to.
    [Spine14v1.brd]
2014-07-11 started routing
    [Spine14v1.brd, Spine14v1.sch]
2014-07-13 Routed most of the ATMega. Can there be traces in the Route2 layer?
    [Spine14v1.brd]
2014-07-13 removed a few traces cuz i didn't realize Top layer was a huge GND polygon. although i fail to see the difference between the Top GND polygon and the Route2 GND polygon
    [Spine14v1.brd]
2014-07-14 routed some more (almost finished). Added some micro swtiches to Jon_LIB
    [Spine14v1.brd, Spine14v1.sch]
2014-07-14 finished JTAG routing. still need to finish the toggle switches
    [Spine14v1.brd, Spine14v1.sch]
2014-07-14 put in toggle switches and finished routing the baord. Added logo and credits
    [Spine14v1.brd, Spine14v1.sch]
2014-07-16 Spine 14v1 boards sent to print house
    [Spine14v1.brd, Spine14v1.sch]
2014-08-20 end of summer push
    [Spine14v1.brd, Spine14v1.sch]

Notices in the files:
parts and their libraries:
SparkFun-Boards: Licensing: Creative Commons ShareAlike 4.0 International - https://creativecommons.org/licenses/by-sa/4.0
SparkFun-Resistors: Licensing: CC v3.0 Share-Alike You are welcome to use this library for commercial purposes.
